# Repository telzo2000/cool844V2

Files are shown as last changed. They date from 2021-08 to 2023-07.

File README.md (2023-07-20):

# cool844V2

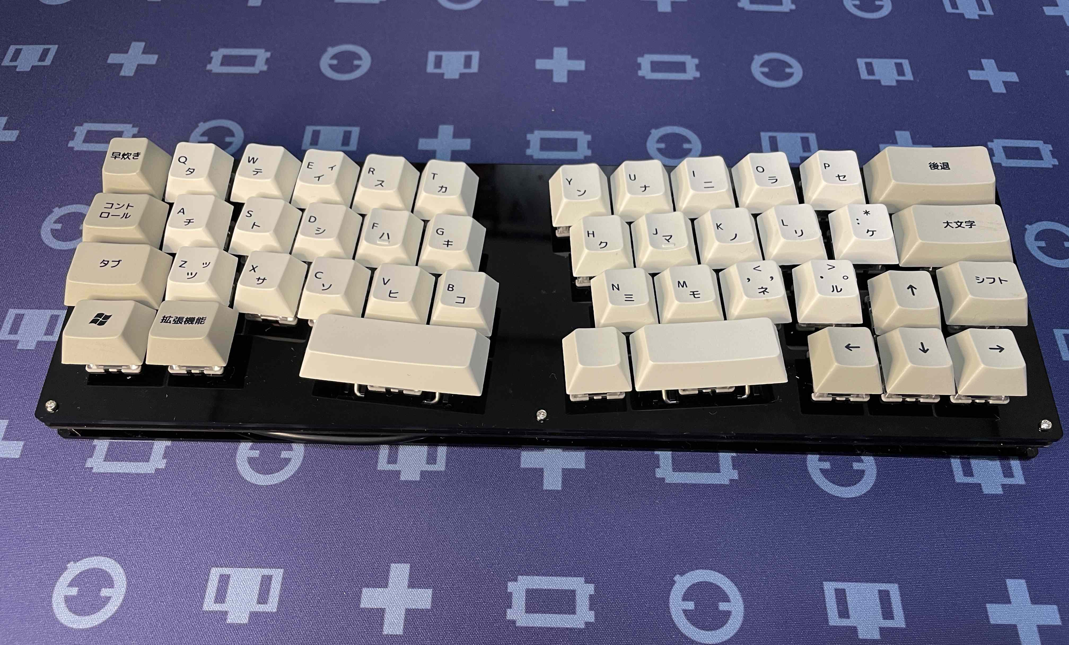
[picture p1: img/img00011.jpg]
<br>
cool844V2は、cool844の改良版を構想する過程で生み出された汎用ケースを使用しない40％アリス配列キーボードです。<br>
余った汎用ケースを再利用する目的で作った、cool844ですが、汎用ケース自体の背の高さから、パームレスト等が必要となり、不便と感じました。<br>
cool844で行った40%アリス配列は、使い勝手が良かったので、さらに使いやすく単体で使うことを構想したのが、cool844V2です。<br>
汎用ケースに収納していたcool844で感じていた高さの問題は、cool844V2でなくなりました。
REMAPによって、自作キーボードにおけるキーレイアウトは簡単に変更できるものとなりました。
これまでもファームウェアを書き換えれば、キーレイアウトの変更は可能であり、市販されているきーボードで感じていた不満を解消できました。
より個人に使いやすく設計されたキーボードとして自作キーボードは残っていくと思います。その一つとして、cool844V2があります。
<br>
今後、LEDの装着方法の見直し、単体として利用ができて、さらに汎用ケースにも収納できるハイブリッドとしての改良を行います。<br>
上記までのcool844V2をver.2.0として、汎用ケースでも、アクリル積層密閉型ケースでも使用できるcool844V2がver.2.1です。<br>
ver.2.1はPCBより下の部分に、ゲタと名付けた部品を介して、汎用ケースに装着できます。気に入った汎用ケースが入手するまでは、標準のアクリル積層密閉型ケースで使用することができます。<br>
ver.2.0もゲタを使用することで、汎用ケースに装着できます。ただし、USBタイプC基板の取り付けが変更になります。また、汎用ケースを使用しない時に、従来のボトムプレートが使用できないので、切り込みの入った別のボトム方レートを使用します。<br>
ver2.0用のゲタとボトムプレートも頒布できるように用意します。<br>
ver.2.1は自分用、最初に用意したものは透明なトッププレートですが、頒布用は黒色となります。ただし、限定ですが、透明なトッププレートも同封した豪華セットも用意します。

<br>
# ビルドガイド

[こちら（ver.2.1）](https://github.com/telzo2000/cool844V2/blob/main/buildguide_for_cool844V21.md)になります。
[English version(ver.2.1)](https://github.com/telzo2000/cool844V2/blob/main/buildguide_for_cool844V21_english.md)
<br>
[こちら（ver.2.0）](https://github.com/telzo2000/cool844V2/blob/main/buildguide_for_cool844V2.md)になります。<br>
<br>

# 今後の予定
20210813 V2(ver.2.0)を頒布しました。<br>
20210815 V2(ver.2.1)を発注しました。<br>
20210830 頒布用にアクリル部品の追加を発注しました。<br>

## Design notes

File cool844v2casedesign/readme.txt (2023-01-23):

These are the components of the keyboard case.
The red line is the cutline.

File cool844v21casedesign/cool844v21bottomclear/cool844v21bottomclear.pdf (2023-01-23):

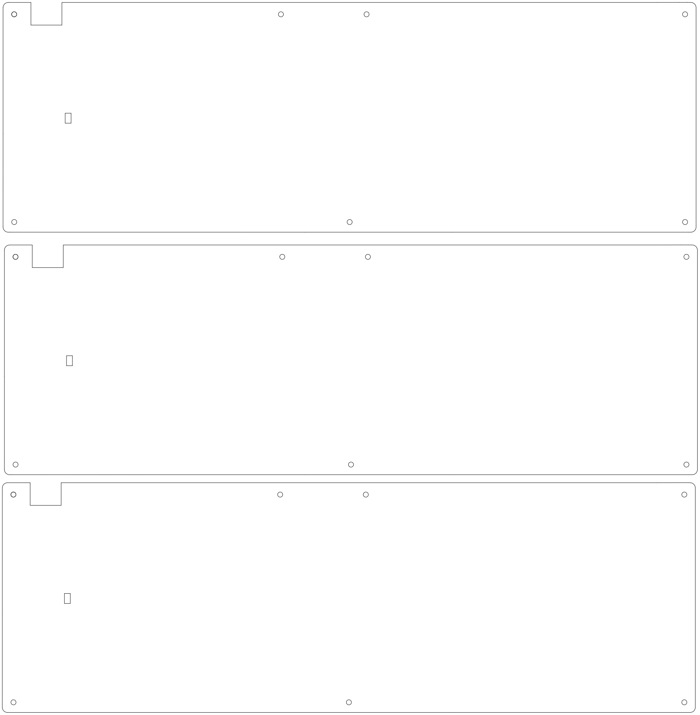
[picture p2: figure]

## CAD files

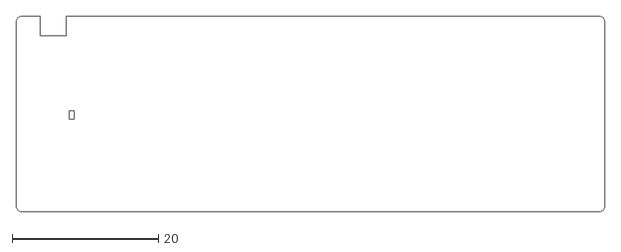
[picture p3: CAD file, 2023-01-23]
cool844v21casedesign/cool844v21bottomclear/cool844v21bottomclear.dxf
80.4 x 26.7

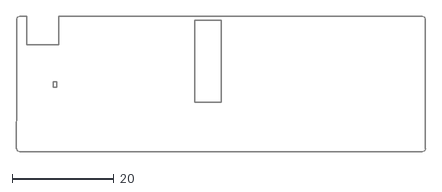
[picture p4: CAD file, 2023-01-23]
cool844v21casedesign/cool844v21getaclear/cool844v21getaclear.dxf
80.4 x 26.7

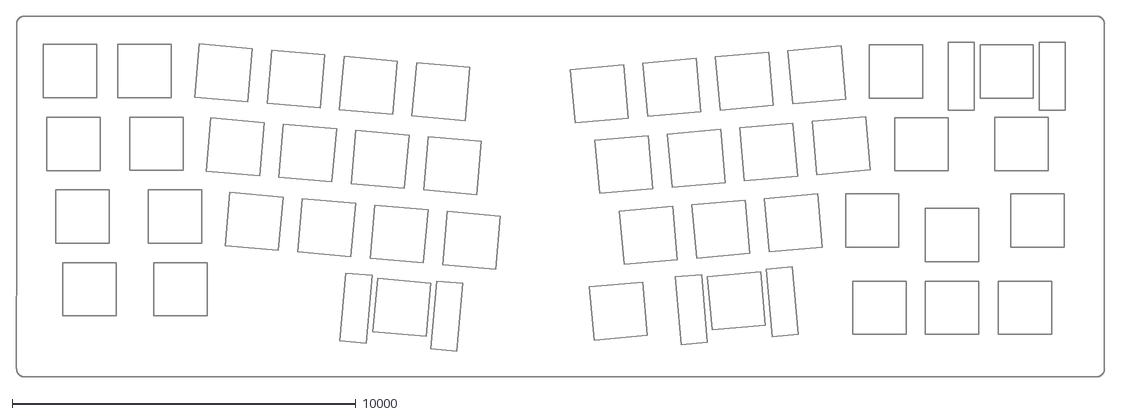
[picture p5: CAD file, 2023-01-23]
cool844v21casedesign/cool844v21topblack/cool844v21topblack.dxf
31667.0 x 10503.3

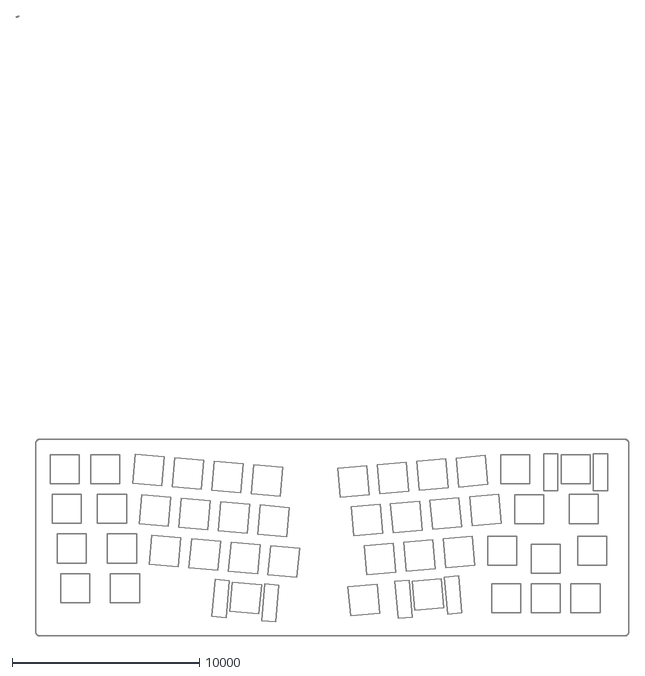
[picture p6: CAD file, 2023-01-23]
cool844v21casedesign/cool844v21topplate/cool844v21topplate.dxf
32707.8 x 33092.1

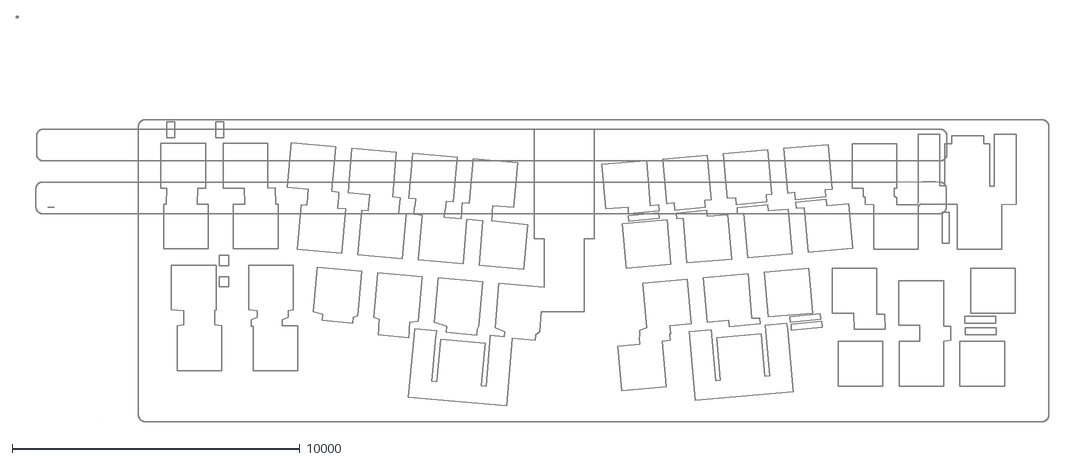
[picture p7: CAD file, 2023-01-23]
cool844v21casedesign/cool844v21topunderplate/cool844v21topunderplate.dxf
35920.0 x 14099.2

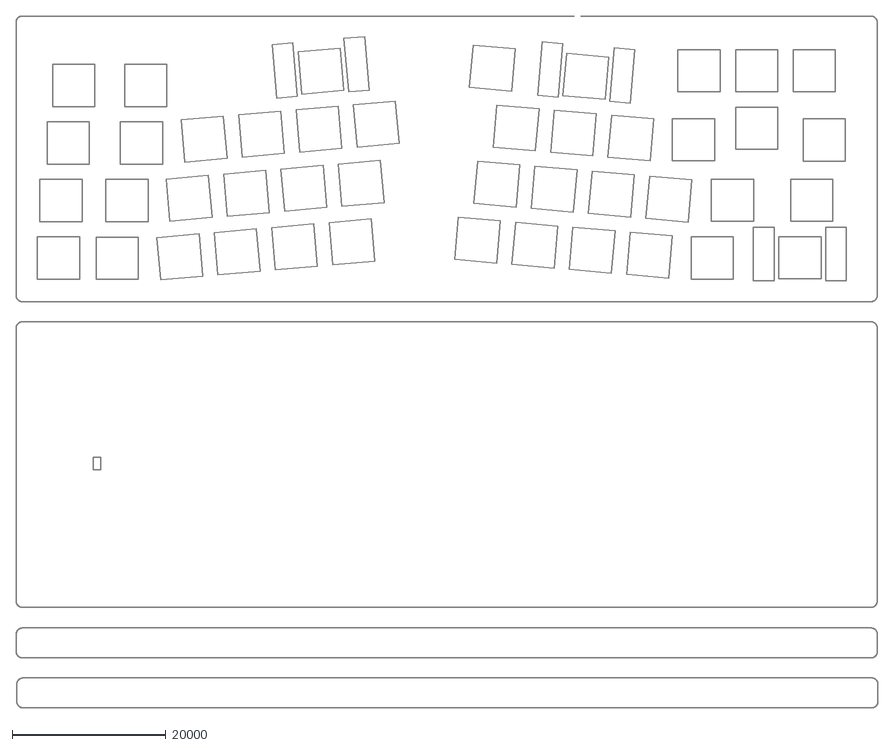
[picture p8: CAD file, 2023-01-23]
cool844v2casedesign/cool844v20case01.dxf
112300.8 x 90138.6

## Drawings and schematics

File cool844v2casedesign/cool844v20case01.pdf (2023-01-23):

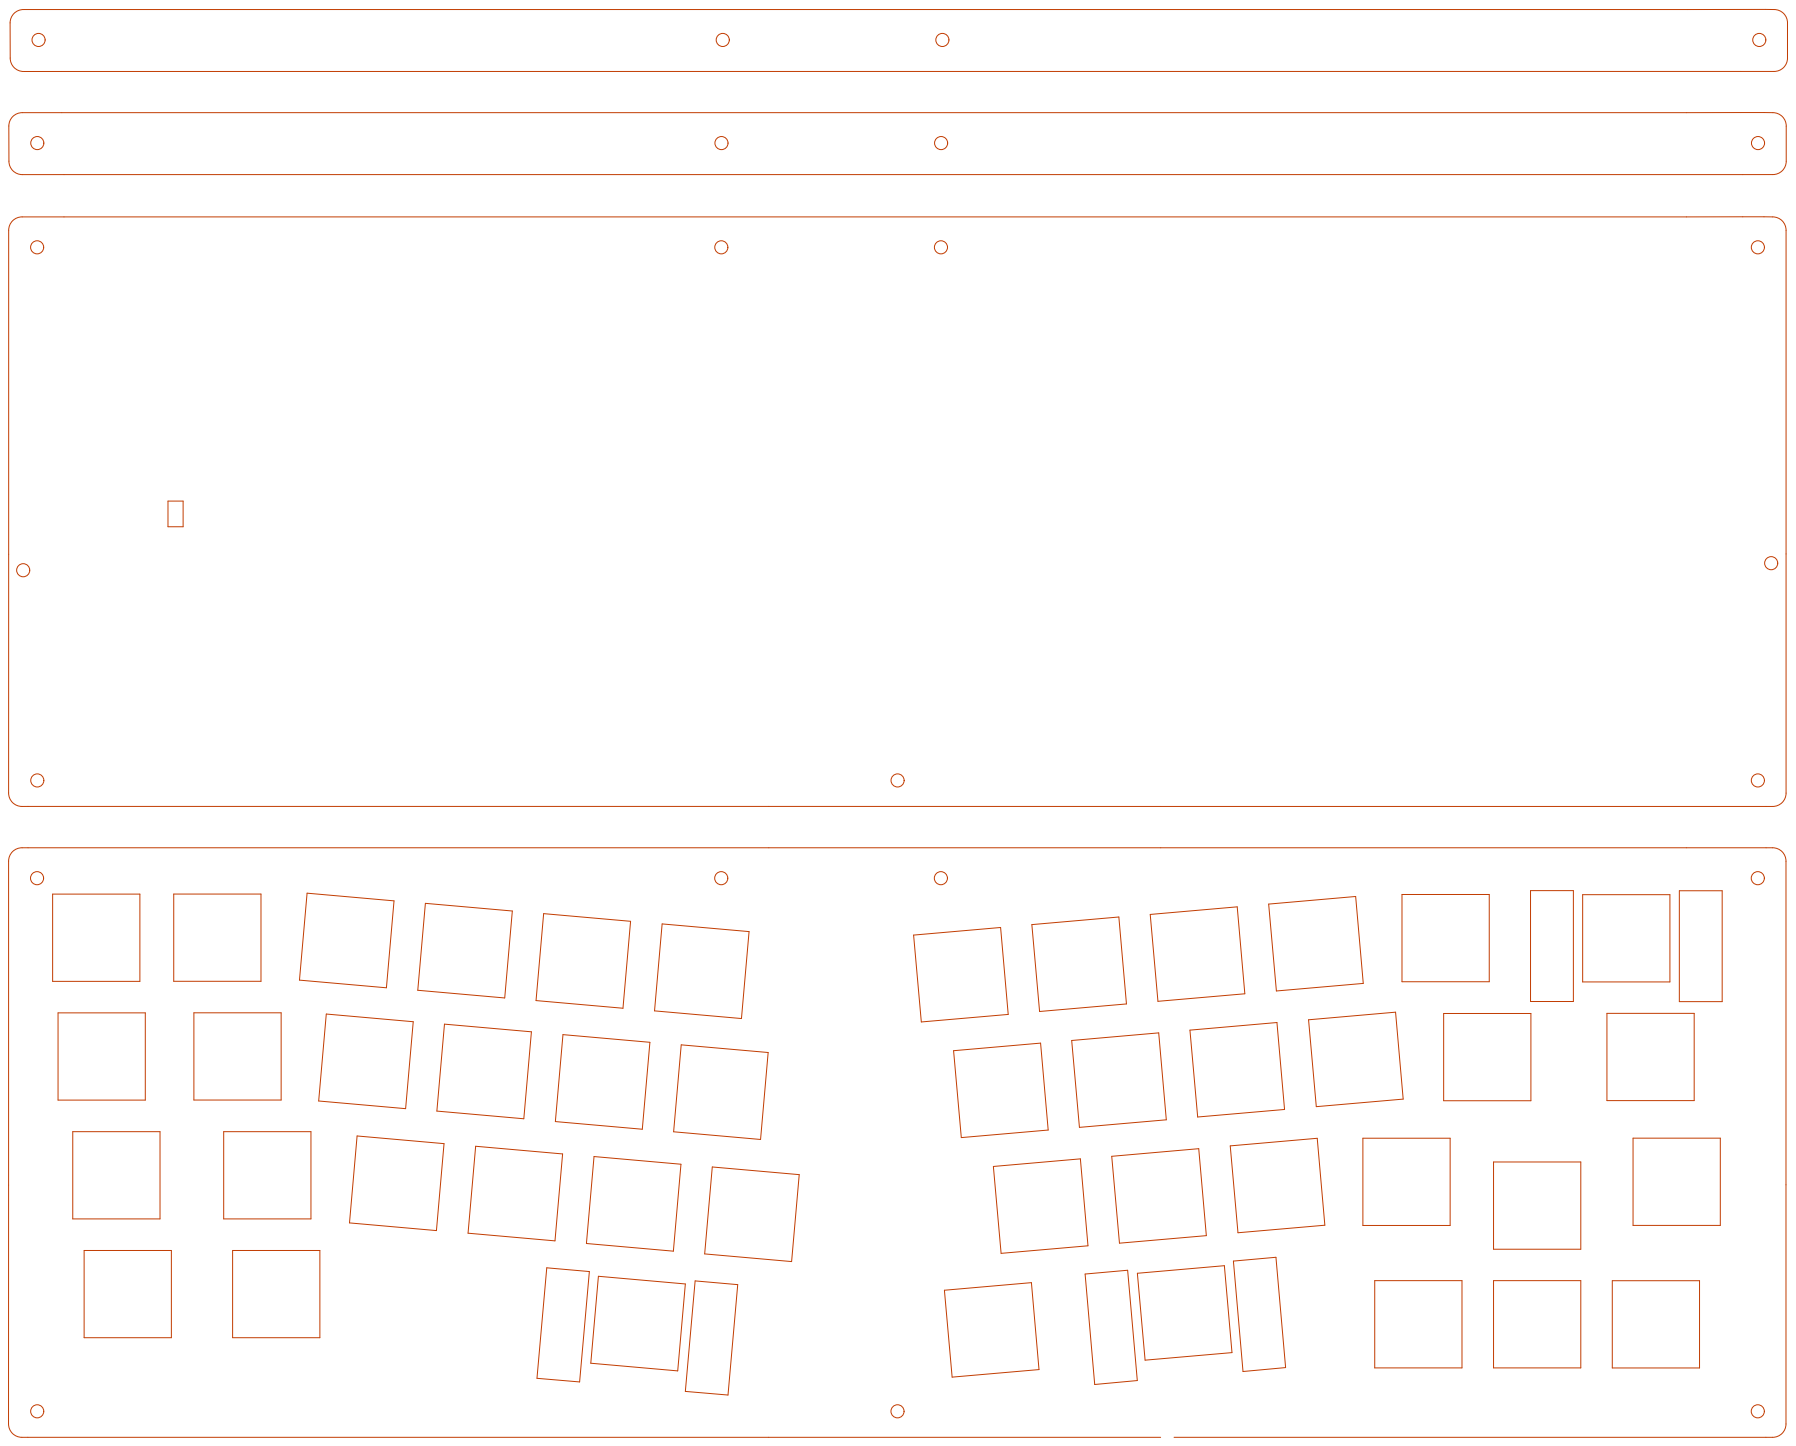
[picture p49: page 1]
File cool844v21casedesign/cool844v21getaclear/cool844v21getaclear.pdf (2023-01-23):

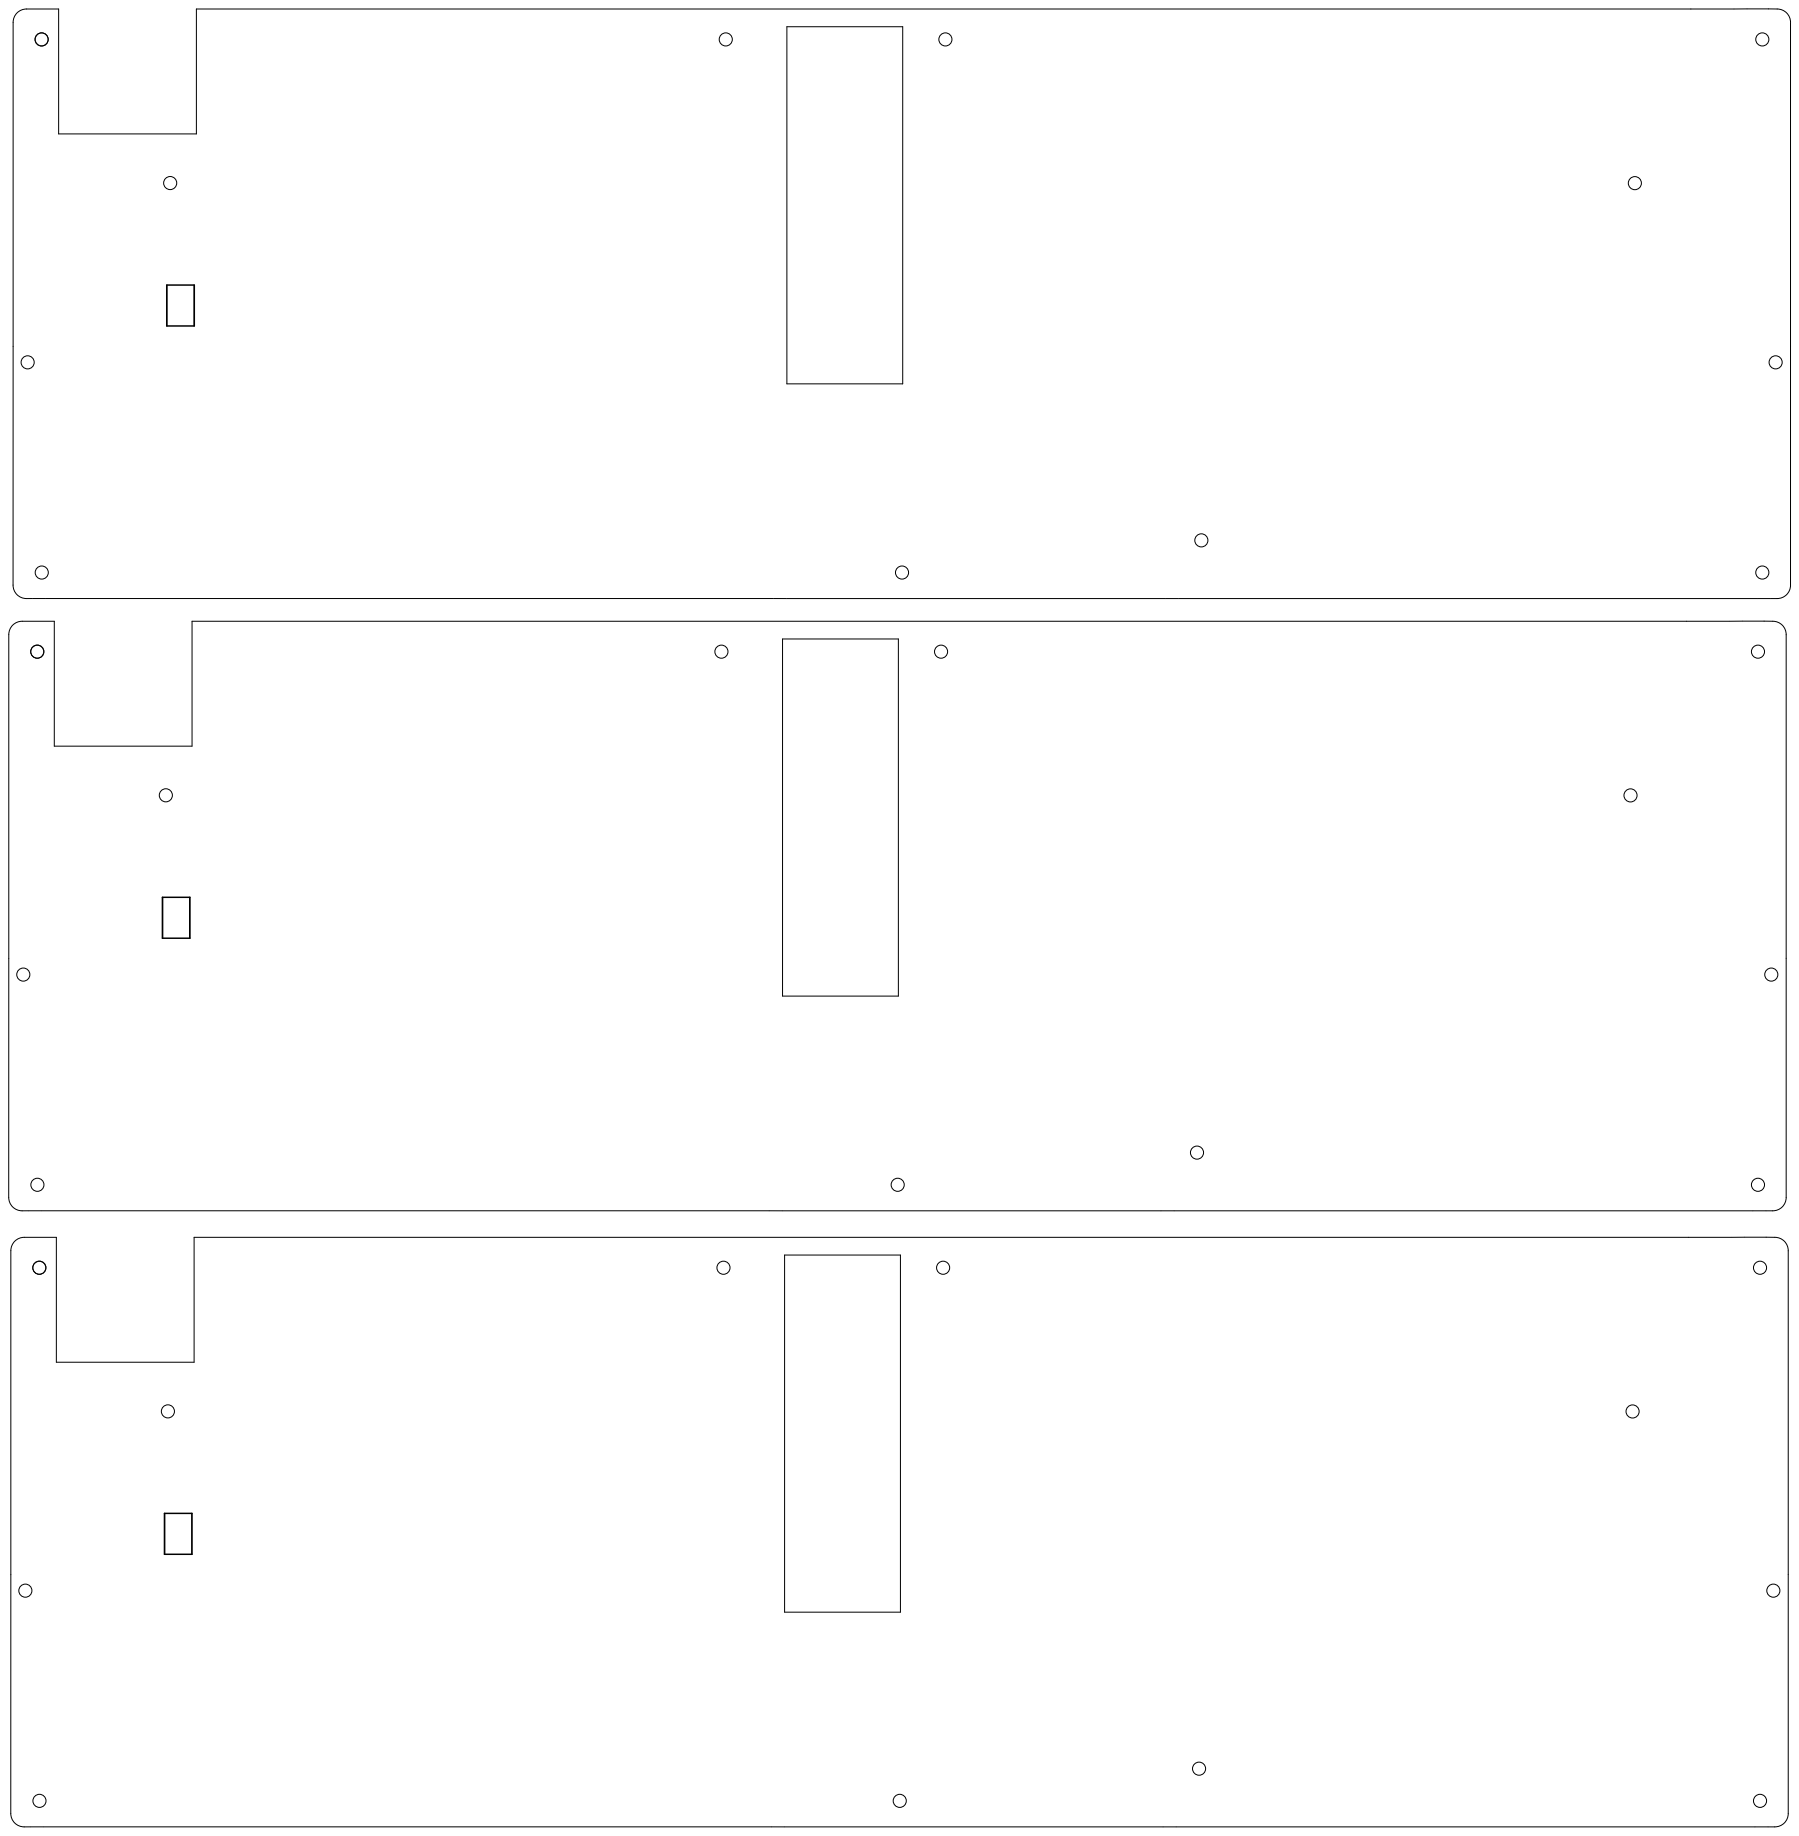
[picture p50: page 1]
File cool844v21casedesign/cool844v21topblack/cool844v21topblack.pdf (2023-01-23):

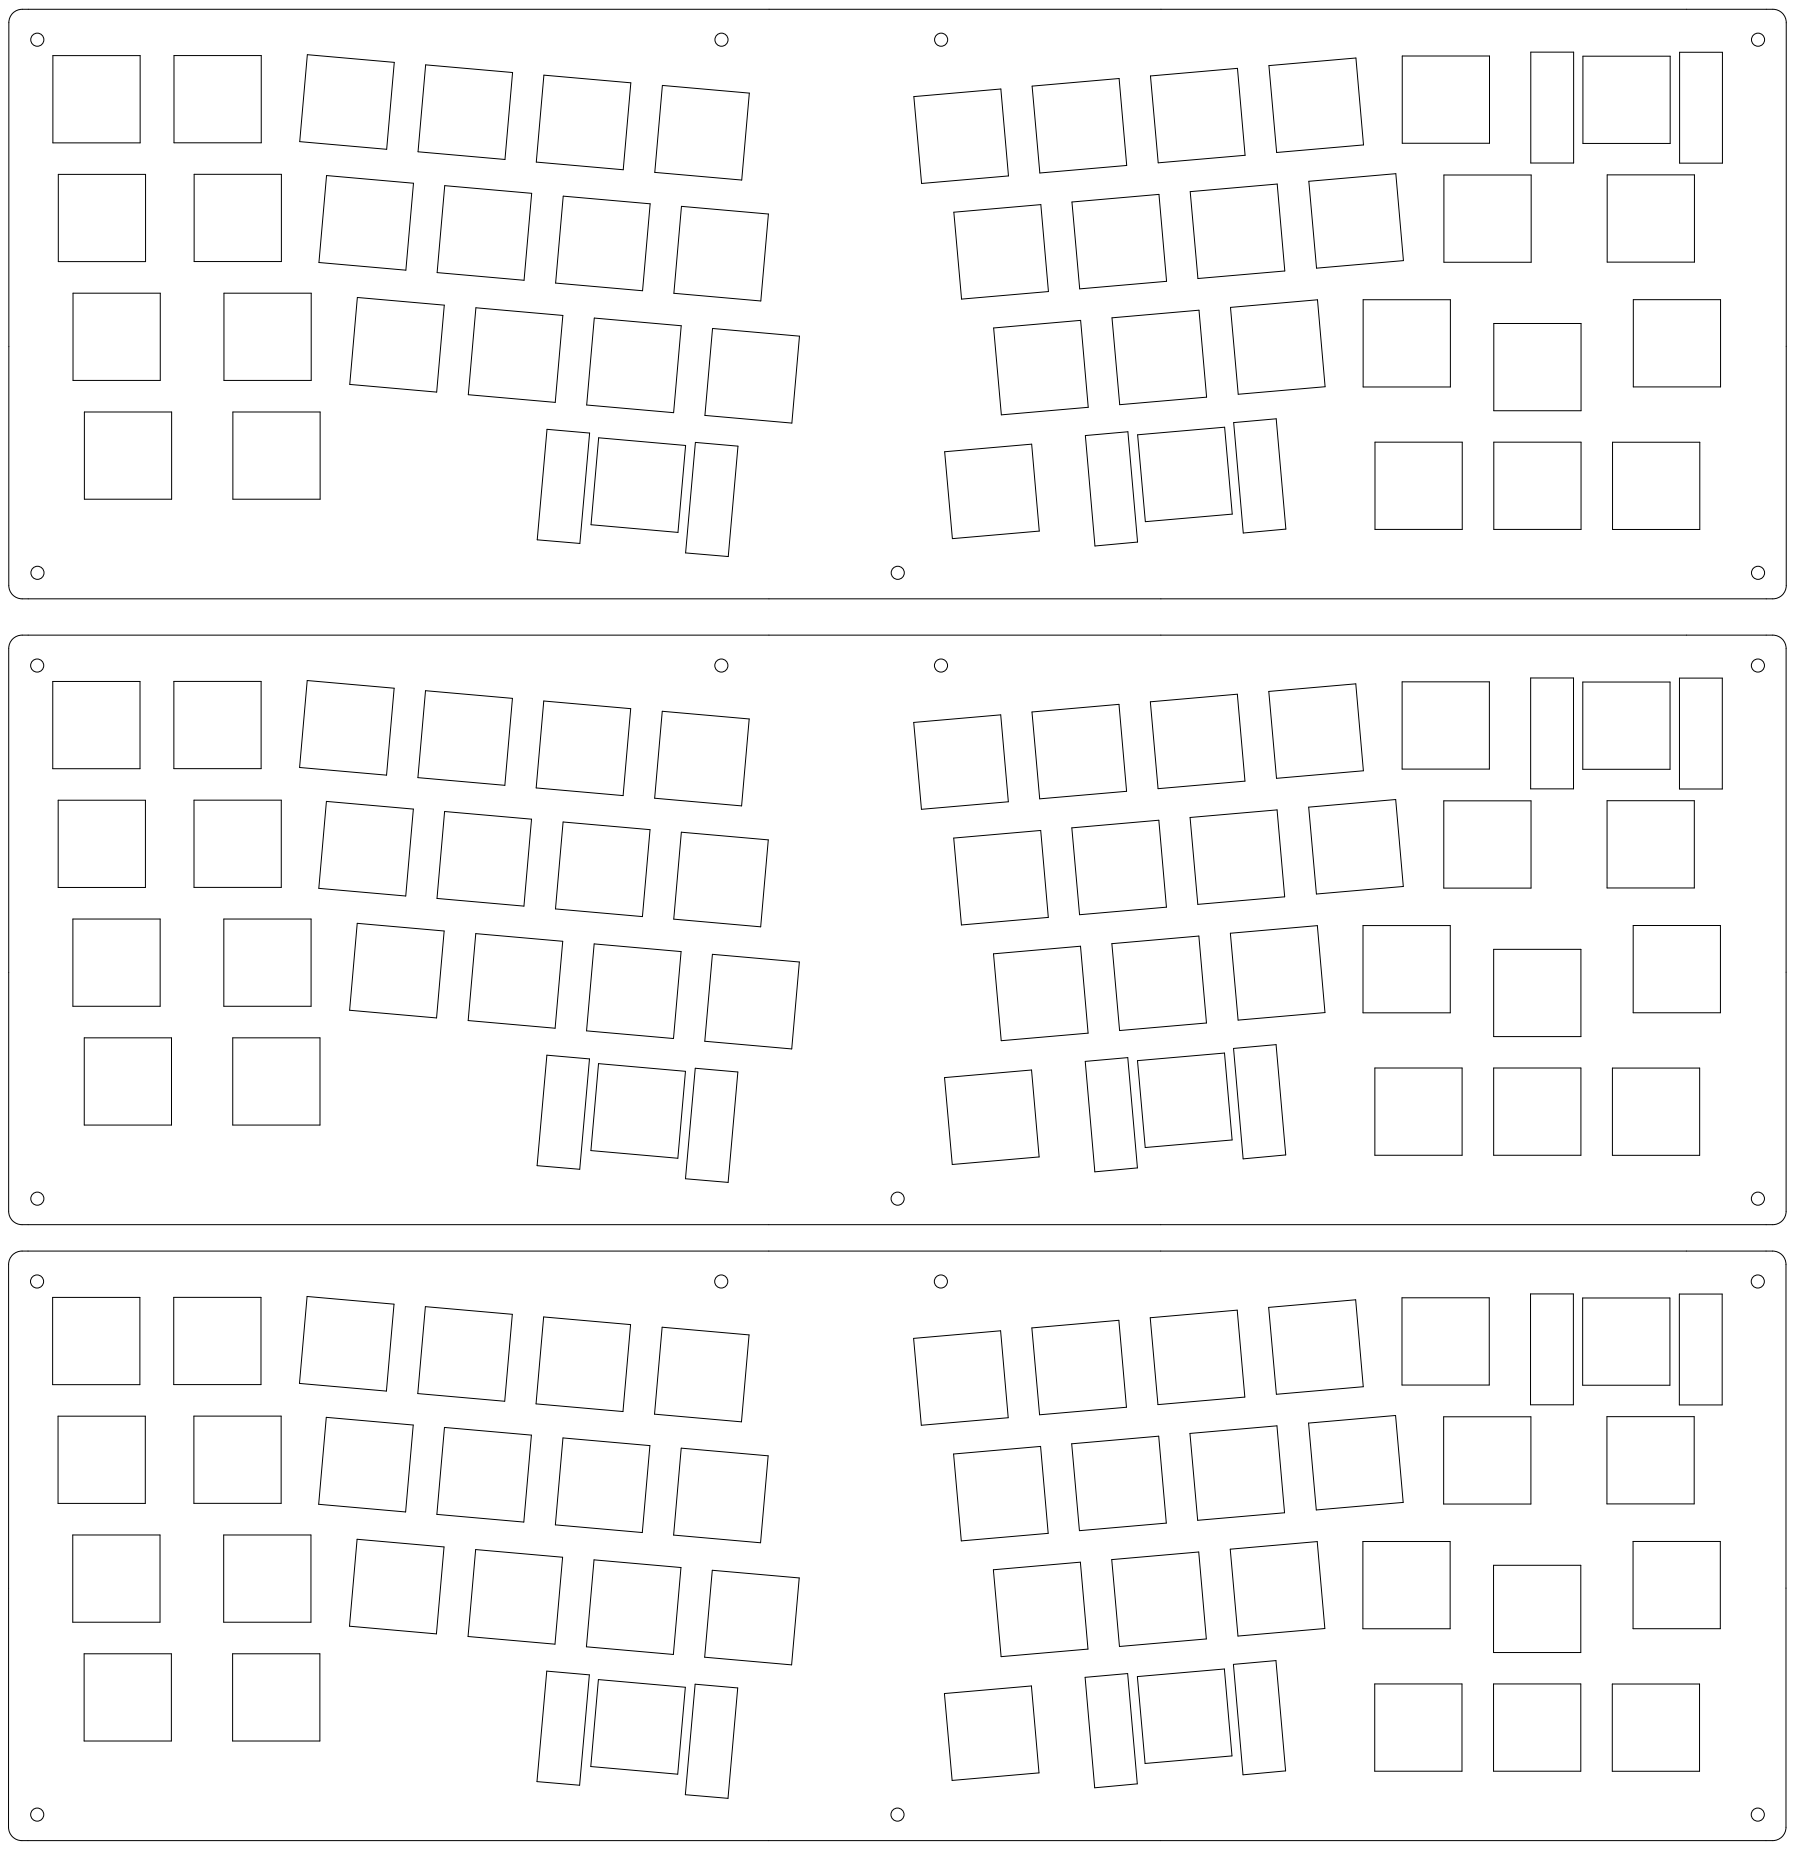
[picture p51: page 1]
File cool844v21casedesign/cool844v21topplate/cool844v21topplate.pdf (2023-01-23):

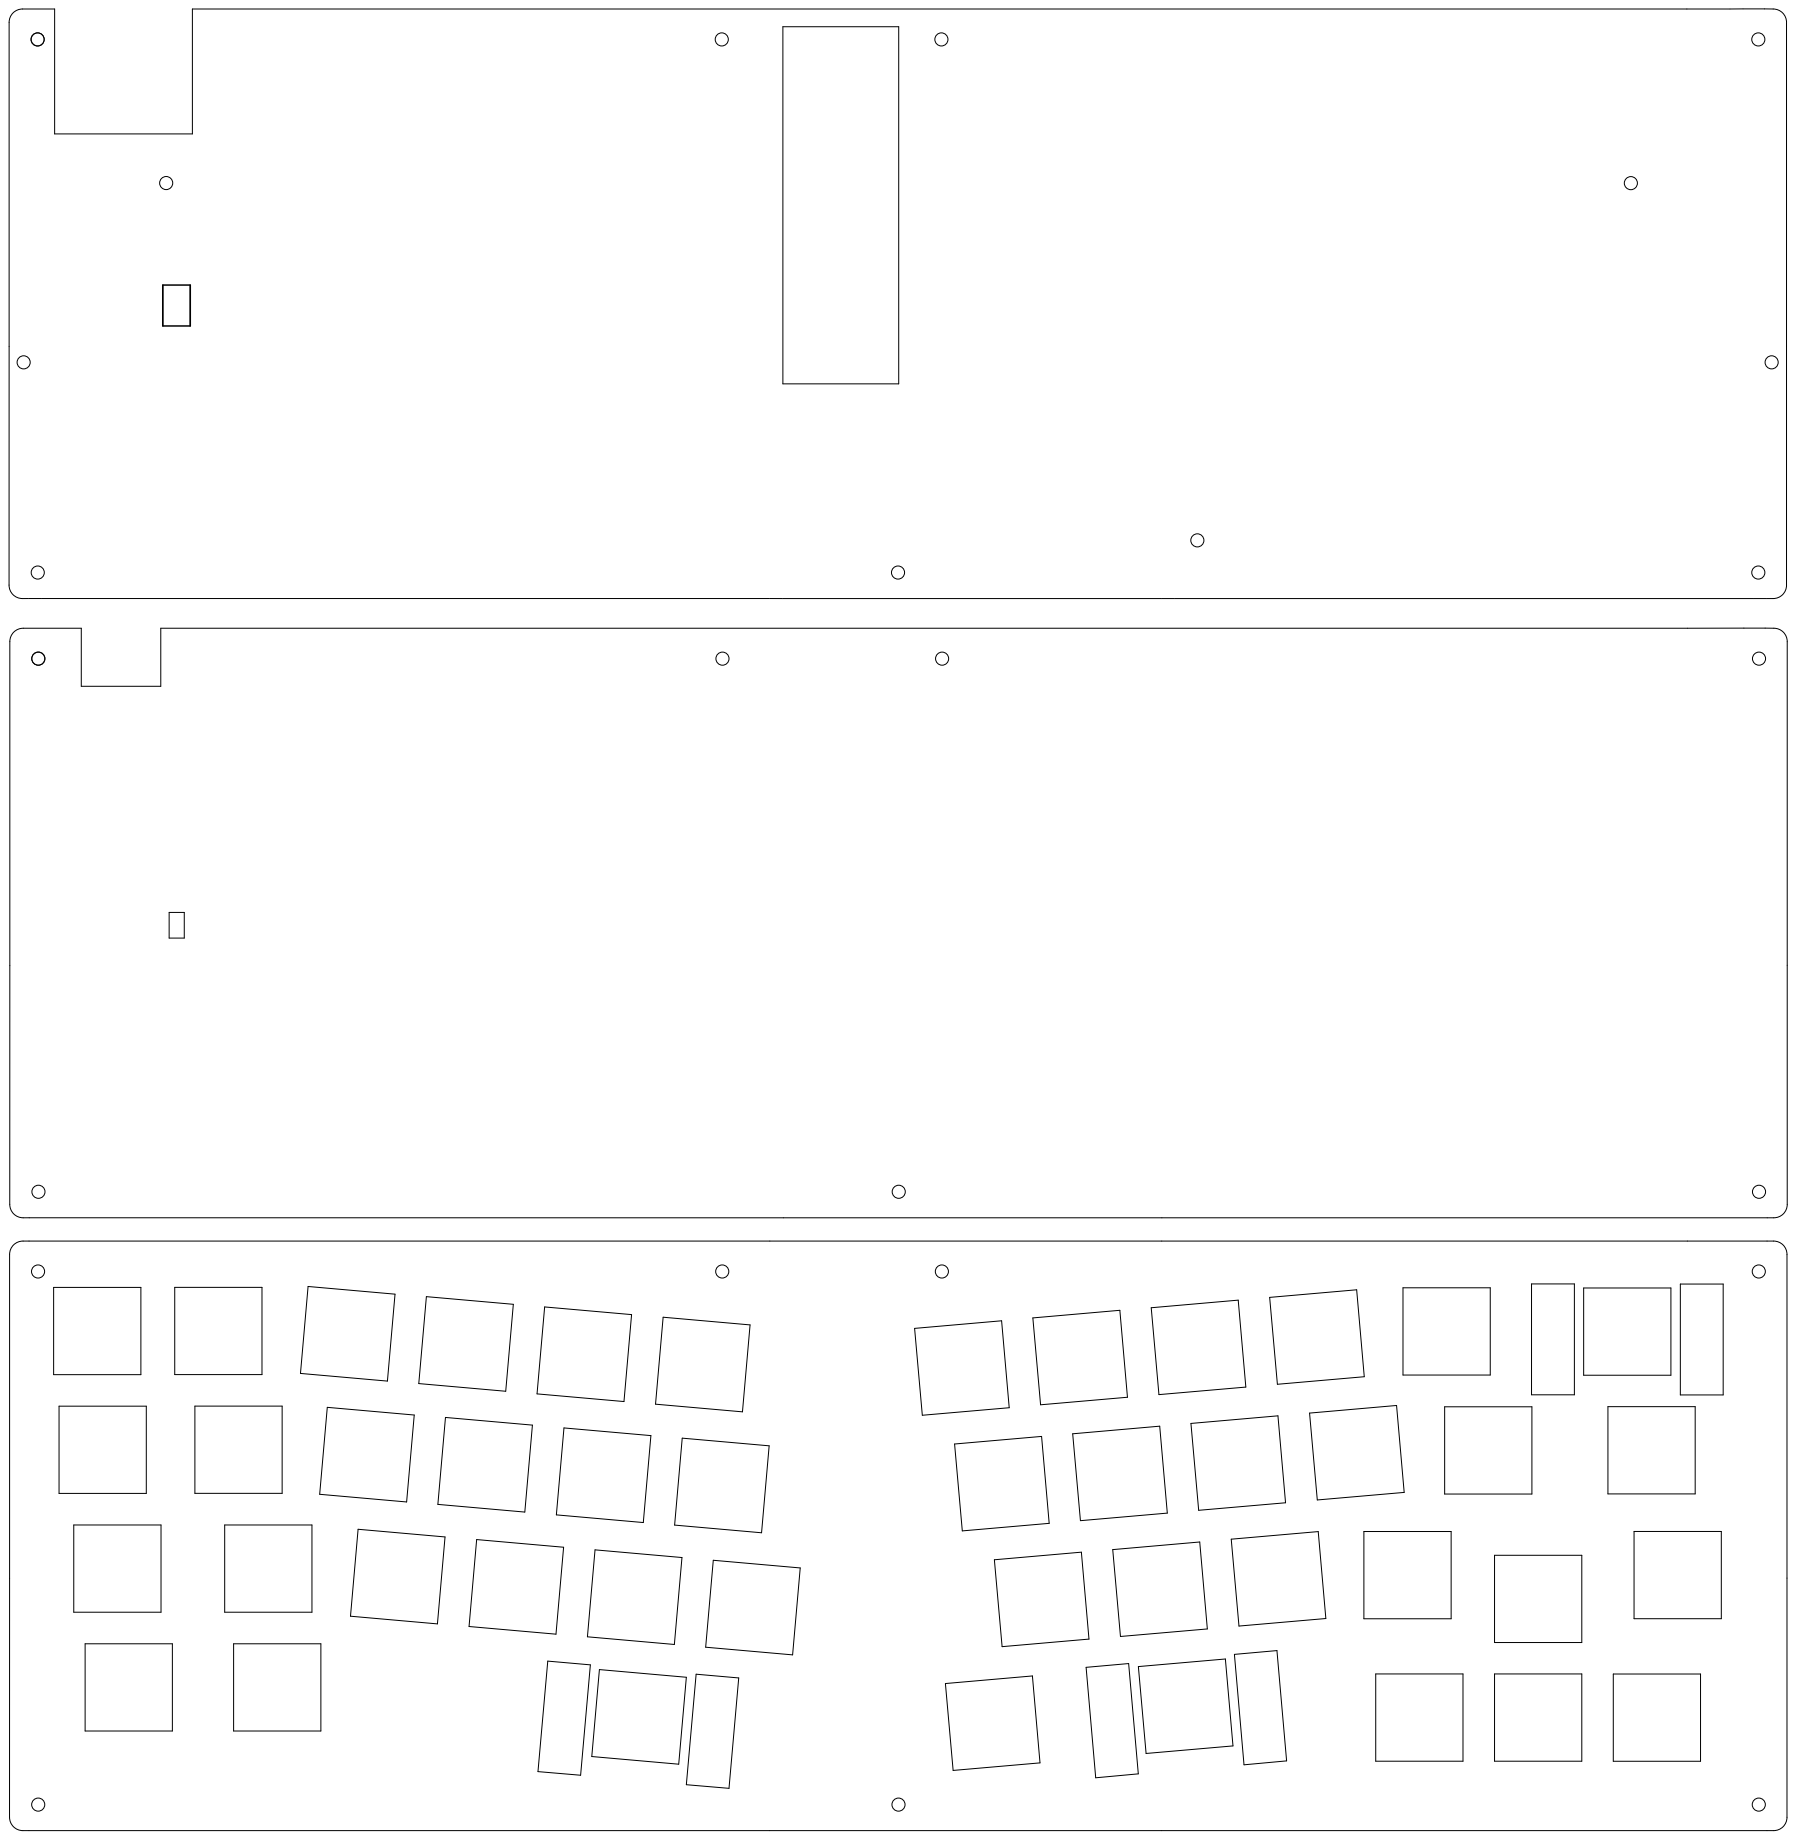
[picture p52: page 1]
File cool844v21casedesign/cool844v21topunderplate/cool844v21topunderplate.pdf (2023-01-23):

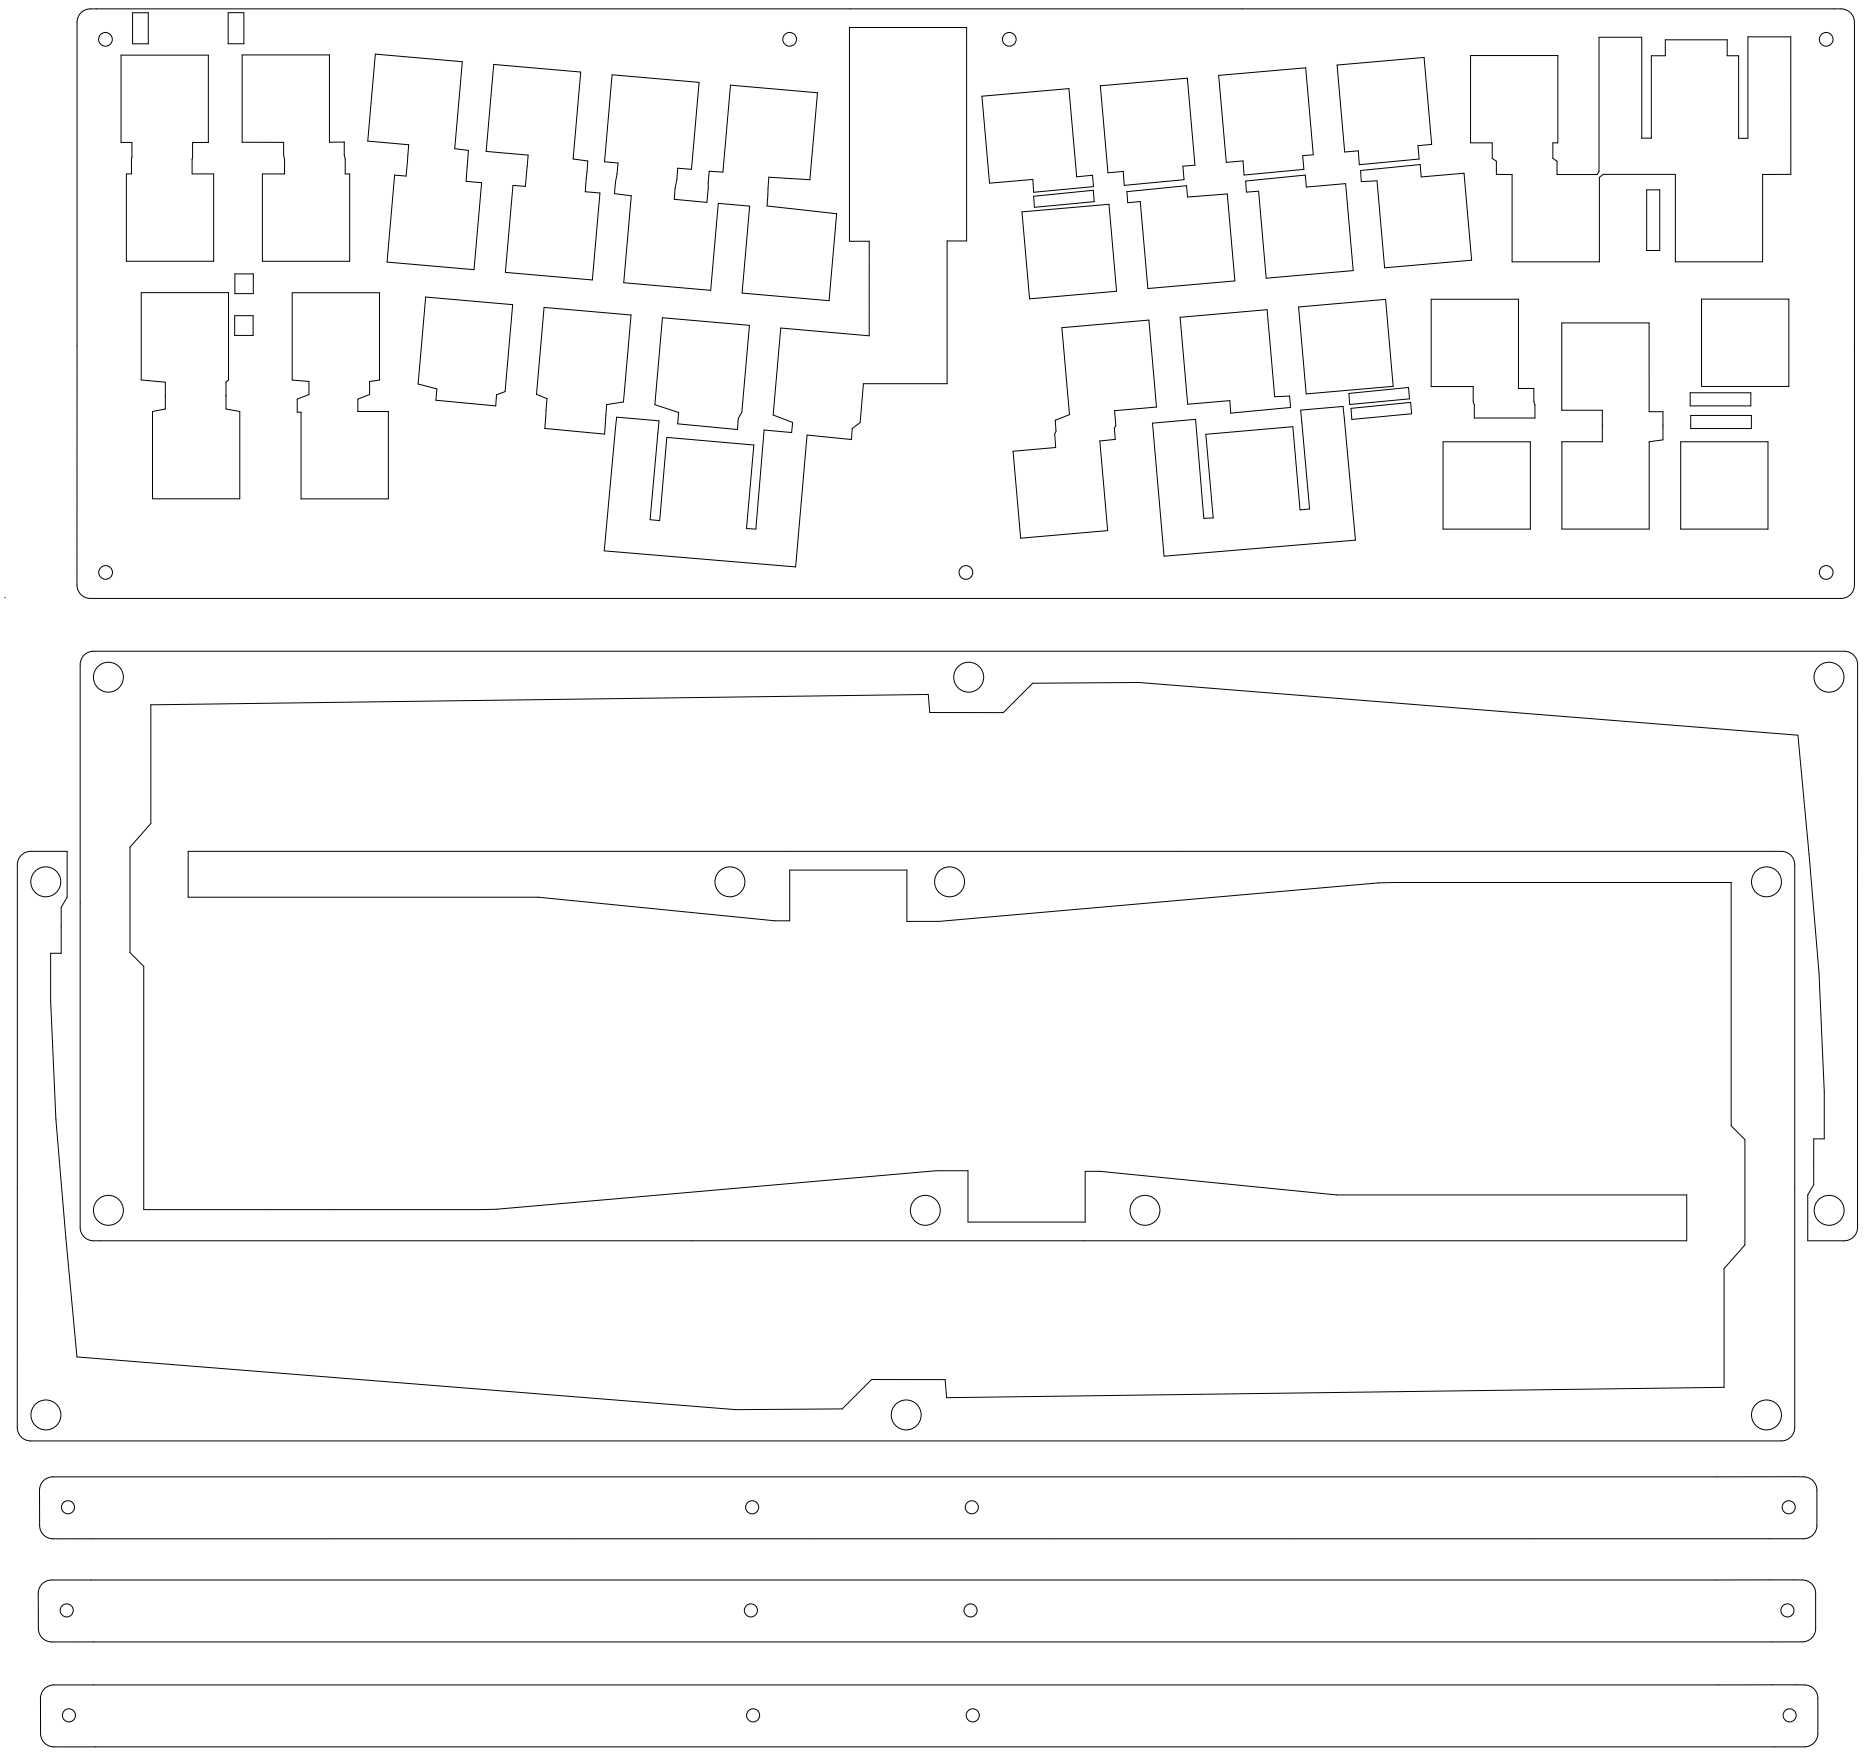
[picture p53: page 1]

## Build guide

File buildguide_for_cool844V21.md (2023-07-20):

# cool844V2ビルドガイド（ver.2.1対応)

### ＜特徴＞
cool844V2（ver.2.1）はm.kiが設計した自作キーボードです。
<br>
60%自作キーボード用の汎用ケースに収納して使うことは、
これまでのcool844と同じです。<br>
また、汎用ケースに収納しないで、単体でも使用できるよう、
アクリルのボトムプレート等が付属しています。<br>
その日の気分によって、気に入った汎用ケースに収納して使ったり、
アクリル積層よる密閉型ケースで使ったりしてください。<br>
<br>

cool844V2　アクリル積層密閉型ケース
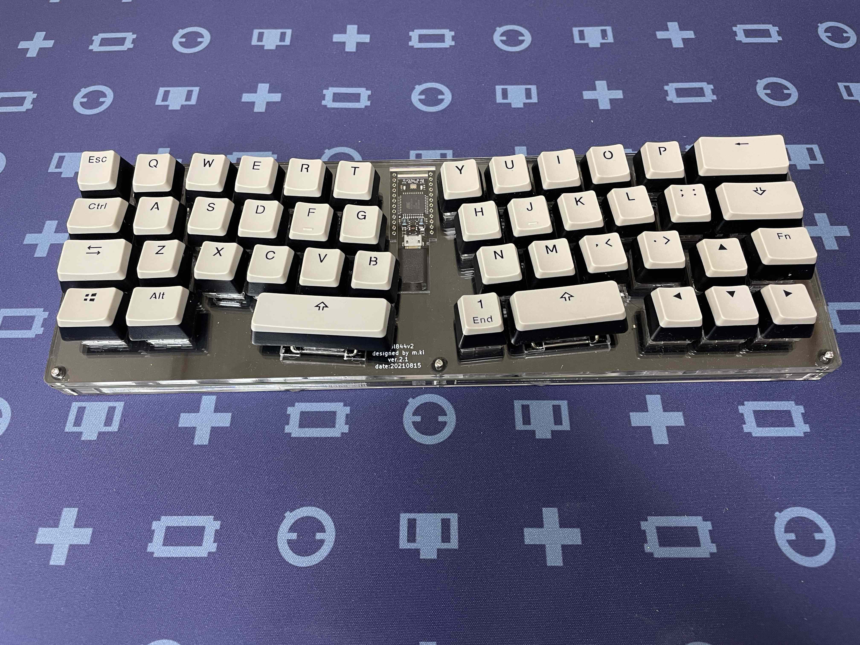
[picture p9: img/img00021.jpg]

cool844V2　別売り60%汎用ケース（木製ケースを使用）
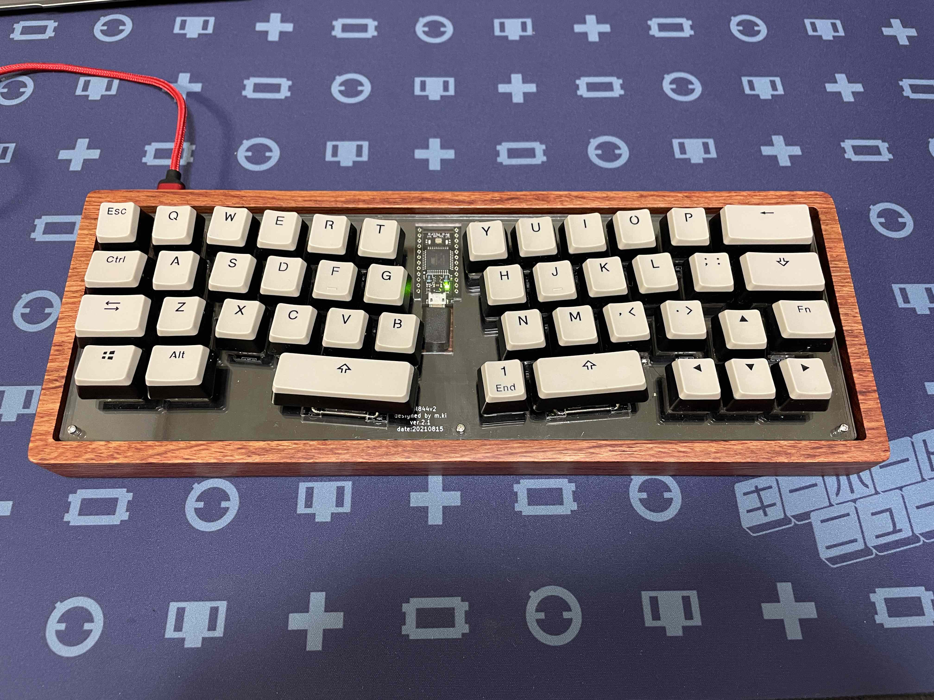
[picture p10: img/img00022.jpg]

cool844V2　ケース収納前
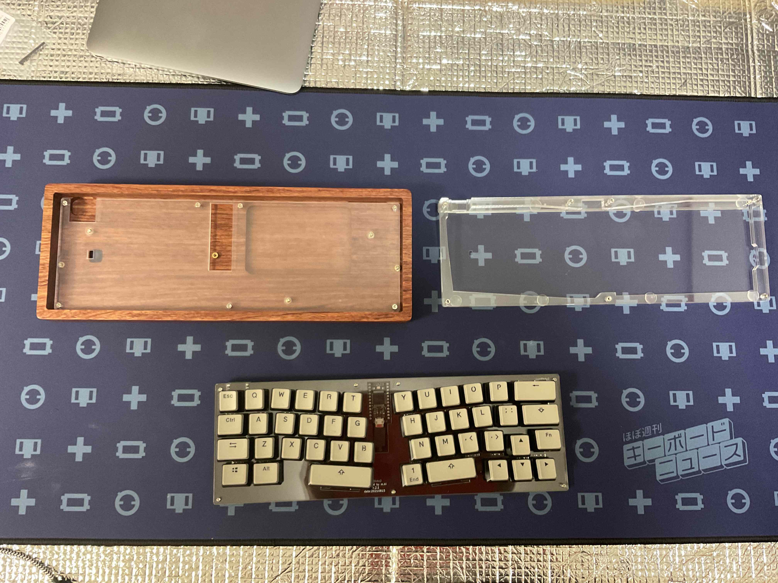
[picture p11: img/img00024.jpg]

注意　上の完成画像で使われている透明なスイッチプレートは、
豪華セットに同封されるものです。<br>
基本セットでは、黒色のスイッチプレートとなり、落ち着いた感じになります。<br>
<br>
# 0　参考
cool844V2は基本、cool844と同じです。組み立てに困りましたら、cool844の[ビルドガイド](https://github.com/telzo2000/cool844/blob/main/buildguideforcool844.md)を参考にしてください。<br>
必ず一読してから、組み立てを行ってください。
<br>

# 1　部品の確認
本品はスイッチプレート、ミドルプレート（２種３枚）、PCB、ボトムプレート大、ボトムプレート小（３枚）、
”ゲタ” 換装用アクリルプレート　１枚、
マイクロUSB端子（オス）付きケーブル、M2スペーサー5.5mm７本、M2ねじ８mm７本、M2ねじ４mm３本、M2ねじ12mm4本で構成されています。<br>
<br>
次のものは各自でご用意ください。<br>
ダイオード（リードタイプ）44個、スイッチソケット44個、リセットスイッチ１個、pro micro１個、スプリングピンヘッダ（マックエイトコンスルー）２個、
スタビライザー２U ３個、USBタイプC基板１個の他、<br>
お気に入りのキーキャップセットとなります。<br>
<br>
60％汎用ケースに換装するときには、<br>
M2スペーサー３mm ７本<br>
M2ネジ４mm　12本<br>
が必要となります。
<br>

<br>

# 2　ダイオードのハンダ付け
PCB基板の下面（基板の右隅に「cool844V2」と印字されている面が上面です）に、「diode」と印字されています。印字されている面から差し込んで、上面からはんだ付けしてください。向きに注意してはんだ付けしてください。<br>
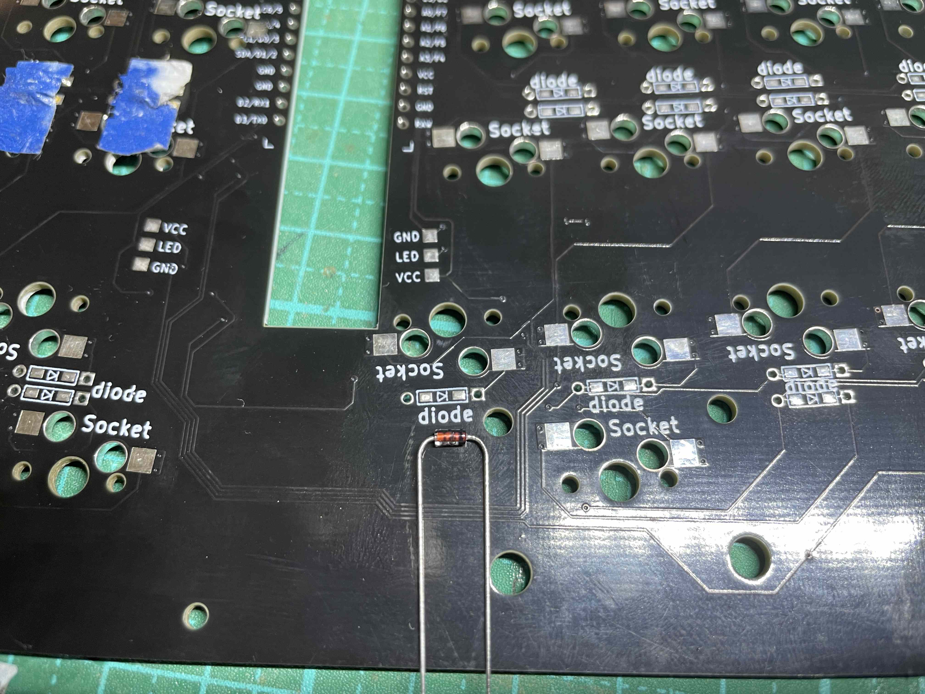
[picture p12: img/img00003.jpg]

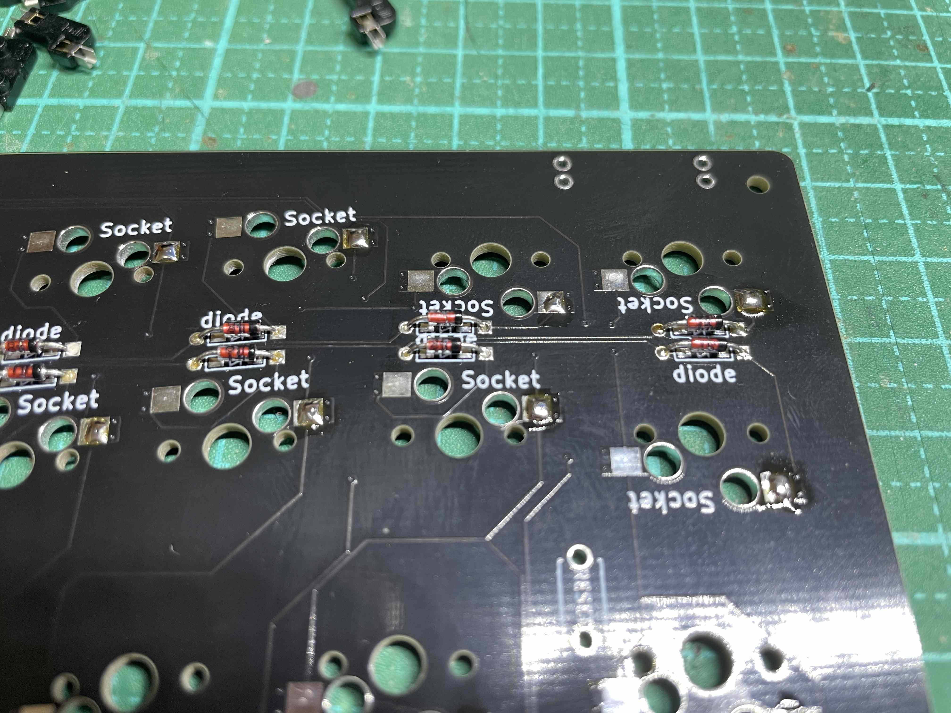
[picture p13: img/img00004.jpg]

<br>

# 3　スイッチソケットのハンダ付け
PCB基板の下面に、「Socket」を印字されています。印字が見えないようにスイッチソケットを乗せて、ハンダ付けをしてください。スイッチソケットには向きがあります。向きを間違えると、キースイッチが入らなくなります。<br>
正しい向きに乗せた場合
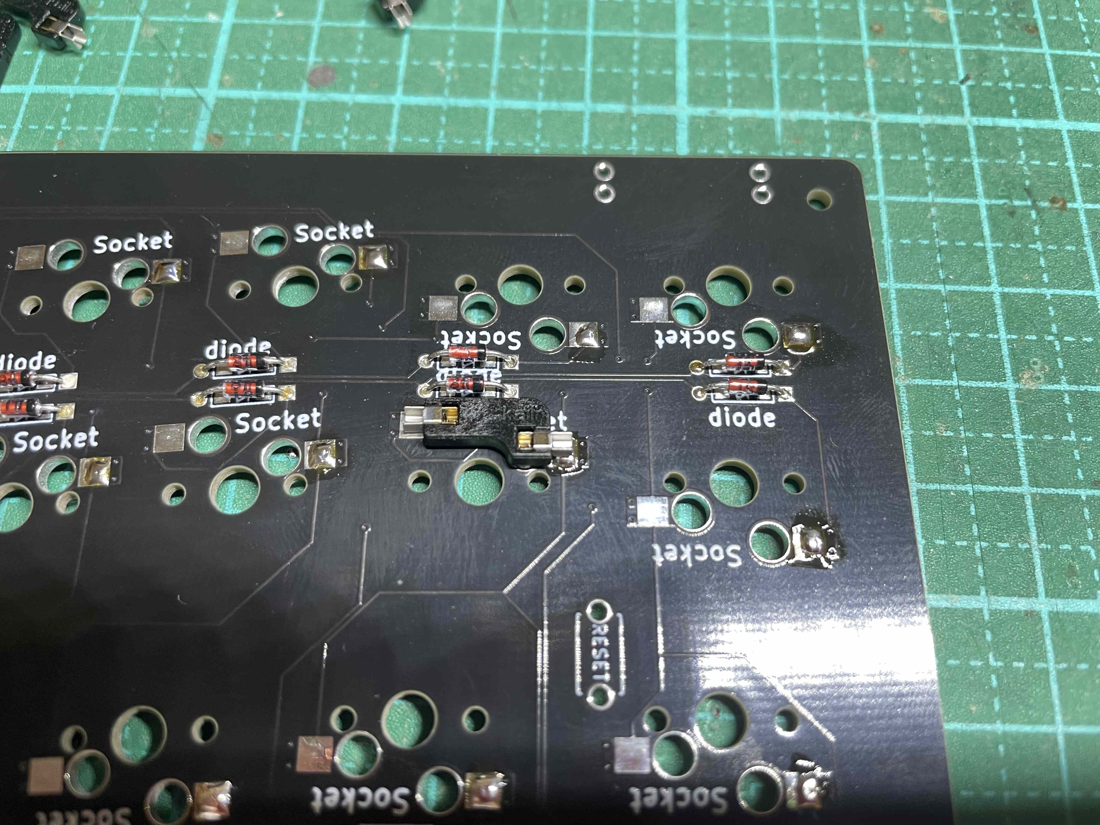
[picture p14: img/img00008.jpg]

間違った向きに乗せた場合（「Socket」の印字が見えます）
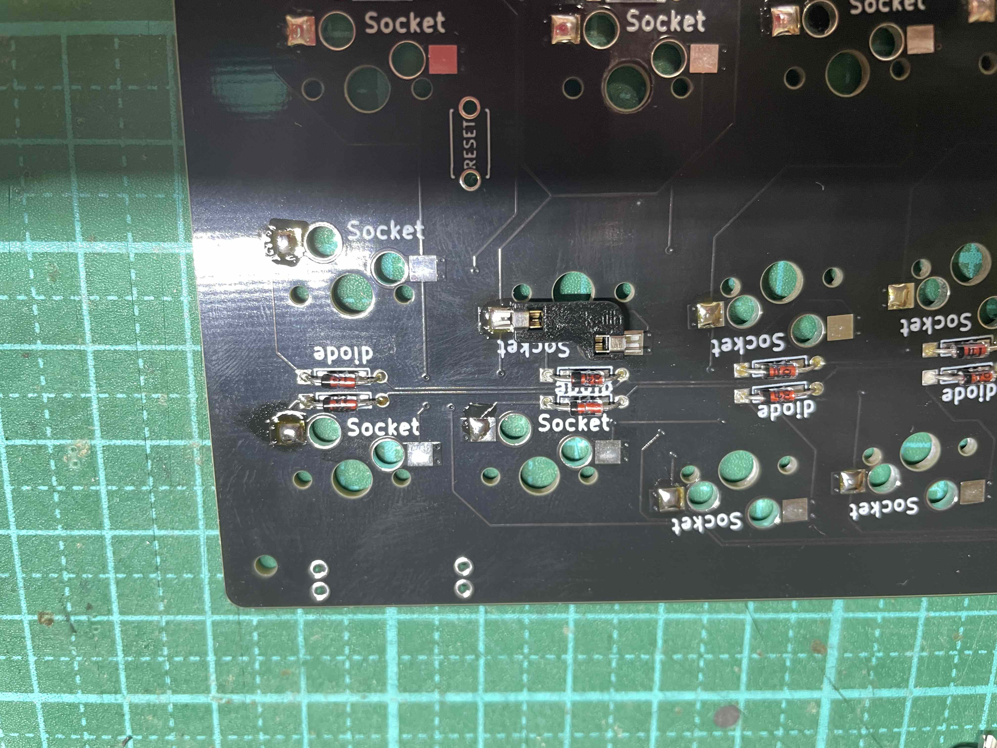
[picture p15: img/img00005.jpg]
間違った向き

<br>
# 4　リセットスイッチのハンダ付け
PCB基板の下面に、「RESET」と印字されています。印字が見ねないようにリセットスイッチを乗せて、上面からハンダ付けをしてください。<br>
<br>
# ５　pro microのハンダ付け
PCB基板の下面に、スプリングピンヘッダ２個をそれぞれ、差し込んでください。<br>
スプリングヘッダには側面に、小さな穴が空いています。
穴が空いている向きを揃える必要があります。
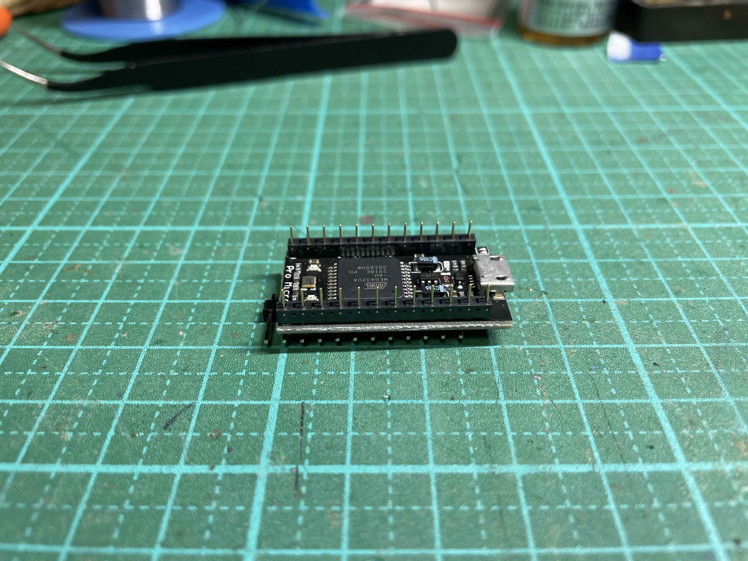
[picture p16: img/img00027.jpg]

スプリングピンヘッダにpro microを差し込んで、pro microとスプリングピンヘッダをハンダ付けをしてください。PCBとスプリングピンヘッダのハンダ付けは不要です。
pro microの向きに注意ください。<br>
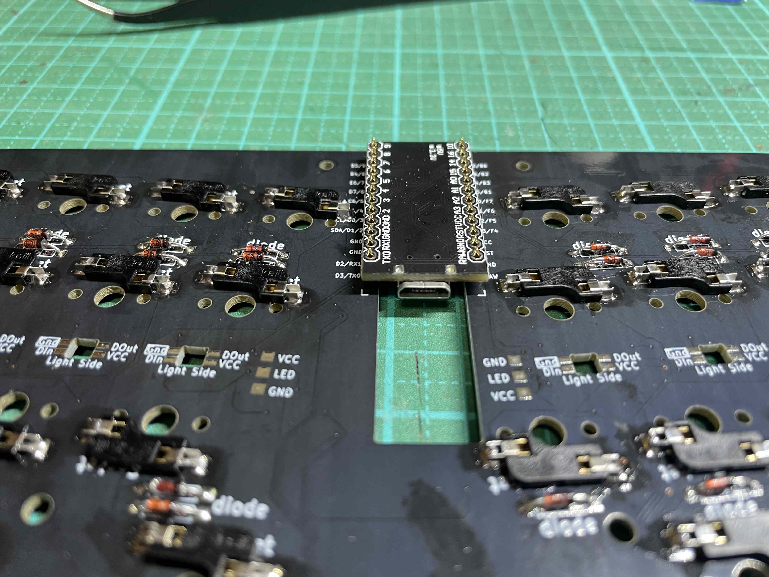
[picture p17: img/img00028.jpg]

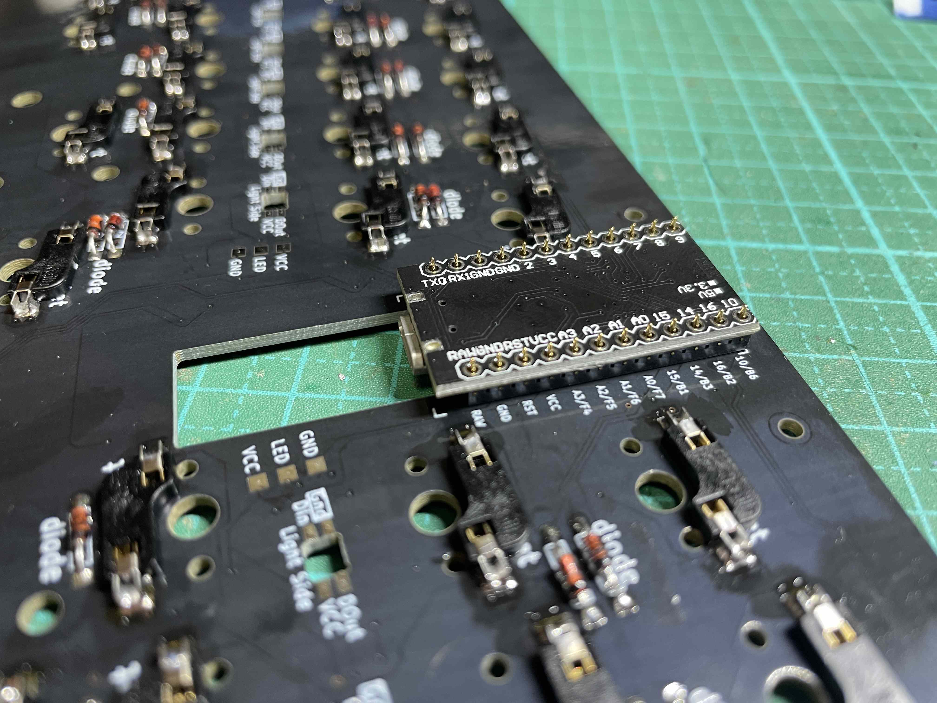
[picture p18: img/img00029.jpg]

<br>
# ６　ドーターボードの作成
付属のマイクロUSB端子（オス）付きケーブルを必要な長さに切ります。<br>
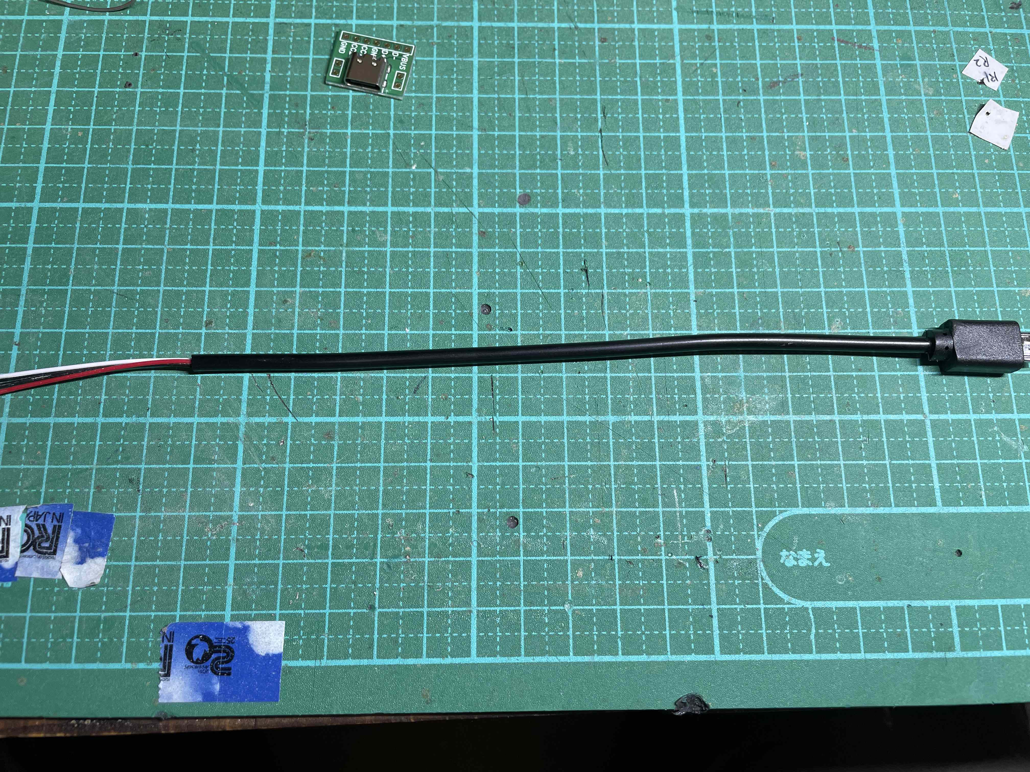
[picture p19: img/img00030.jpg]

最初に端子側から19cmほどのところで切ります。
その後、黒い皮膜が16cmほど、その先は３cmほど残してください。<br>
４色に分かれているケーブルの皮膜を剥いて、それぞれをUSBタイプC基板の端子にハンダ付けしてください。
赤色をVBUS、白色をD-、緑色をD+、黒色をGNDにつないでください。
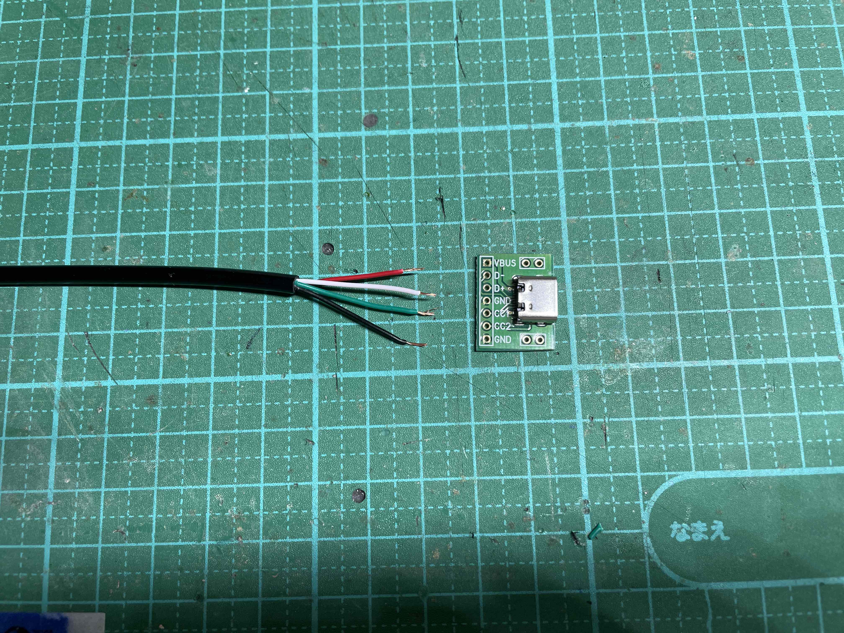
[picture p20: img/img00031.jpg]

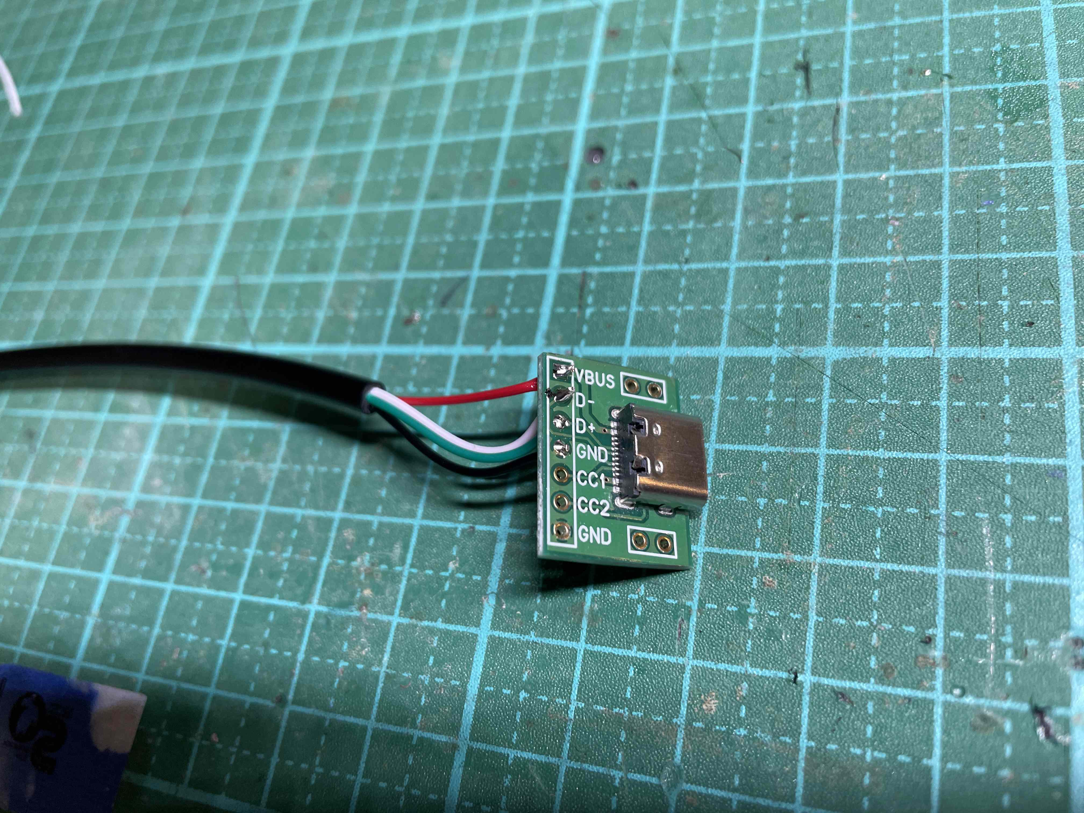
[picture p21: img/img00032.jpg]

次に、USBタイプC基板をPCBにハンダ付けで固定します。<br>
最初にピンヘッダをUSBタイプC基板側に取り付けてください。
次の画像を参考にしてください。
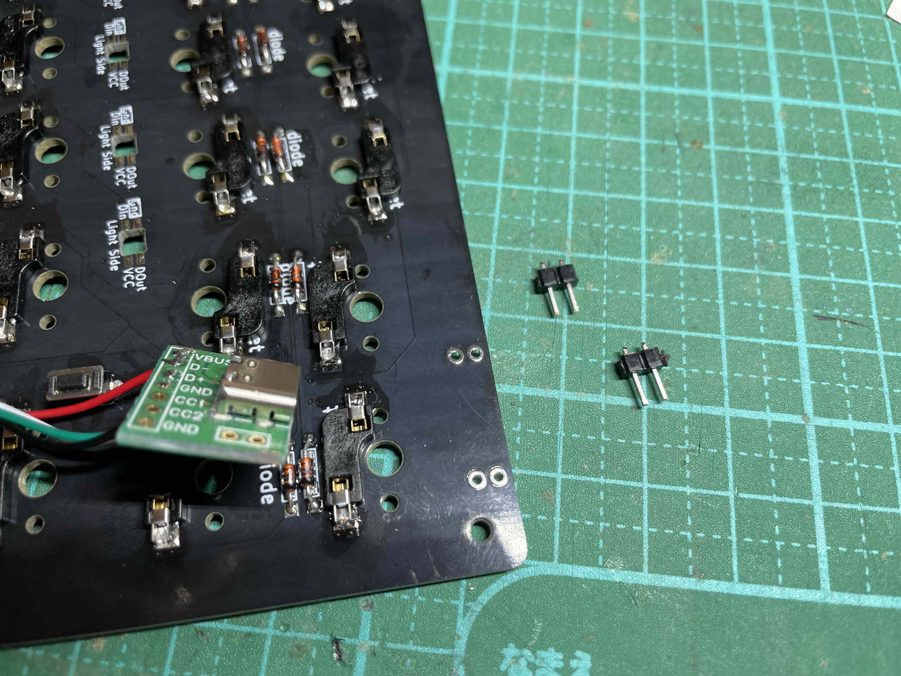
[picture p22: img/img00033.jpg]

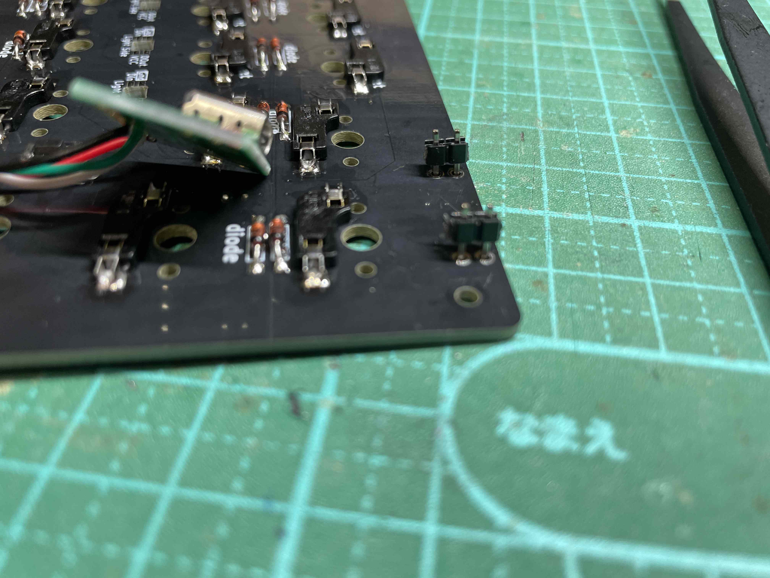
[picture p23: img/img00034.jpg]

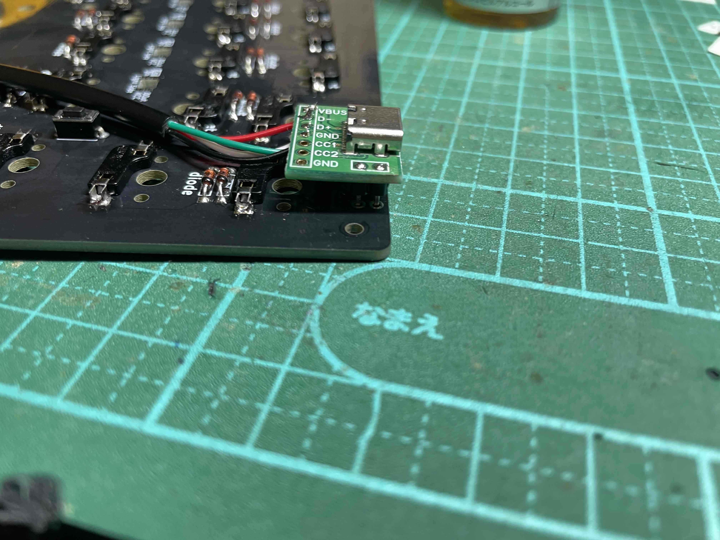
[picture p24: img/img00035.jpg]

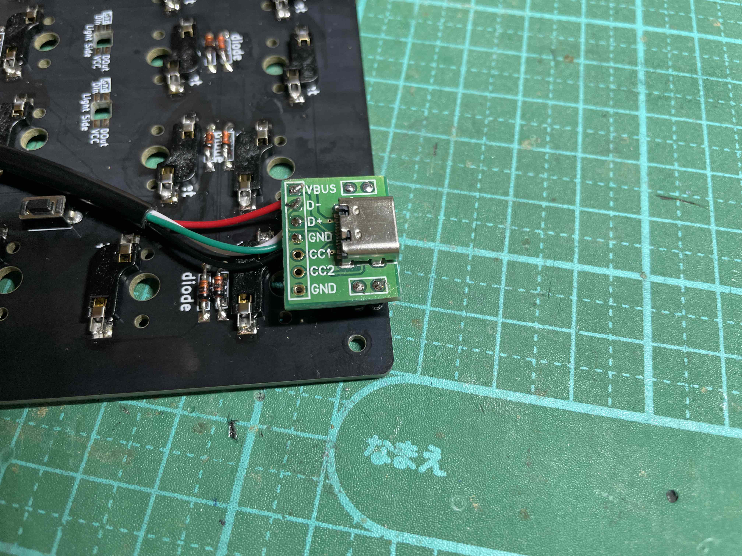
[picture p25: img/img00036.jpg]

次にPCB側にハンダ付けをしますが、その前に、
ミドルプレート下２枚、ボトムプレート大、ボトムプレート小１枚を
仮組みして、USBタイプC基板のハンダ付け位置を確認します。
この時、USBタイプC基板の個体差の関係で、幅が大きく、ミドルプレート下に干渉する場合、基板の両端部をヤスリで削ってください。<br>
次の画像を参考にしてください。

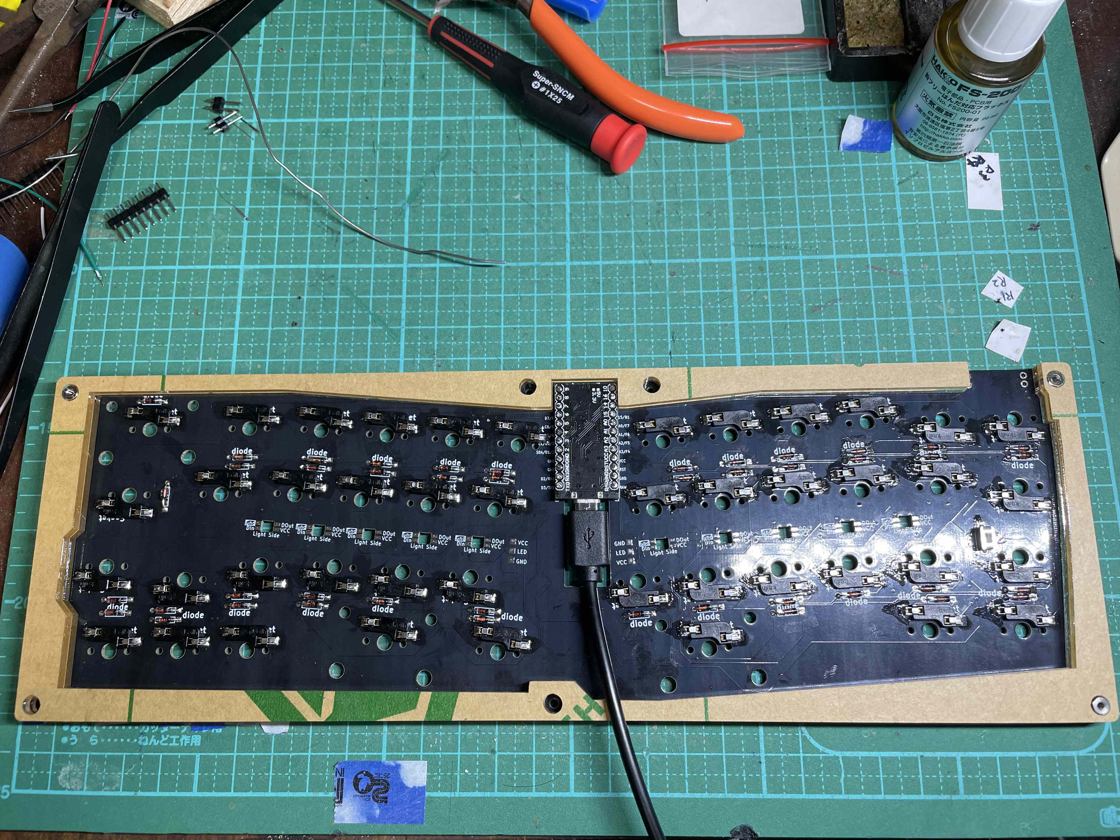
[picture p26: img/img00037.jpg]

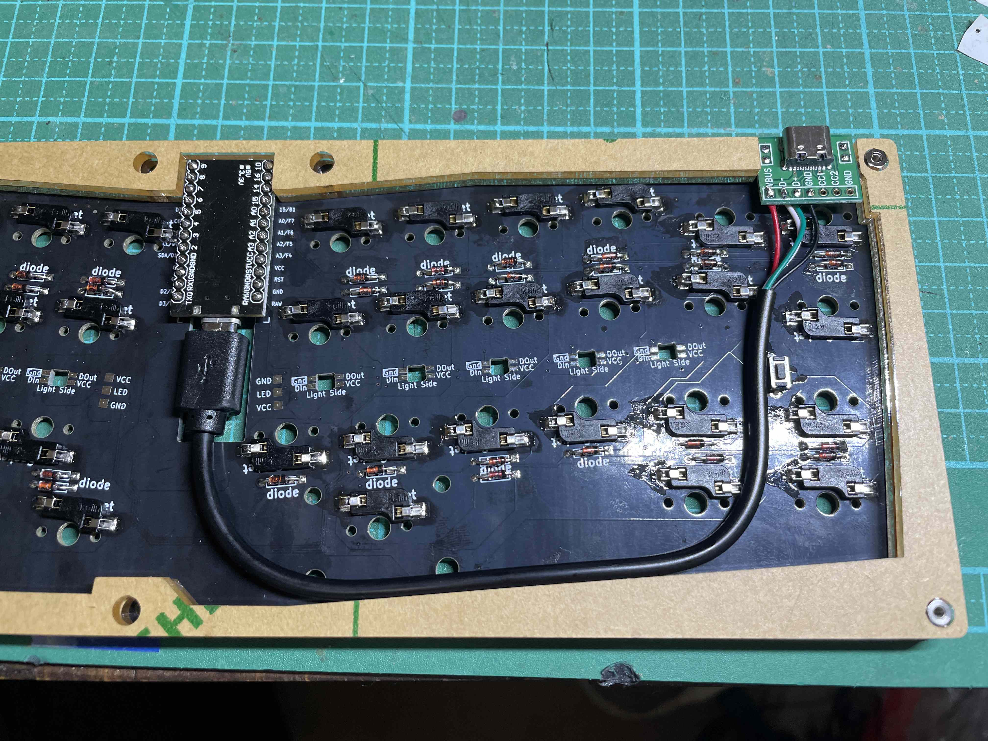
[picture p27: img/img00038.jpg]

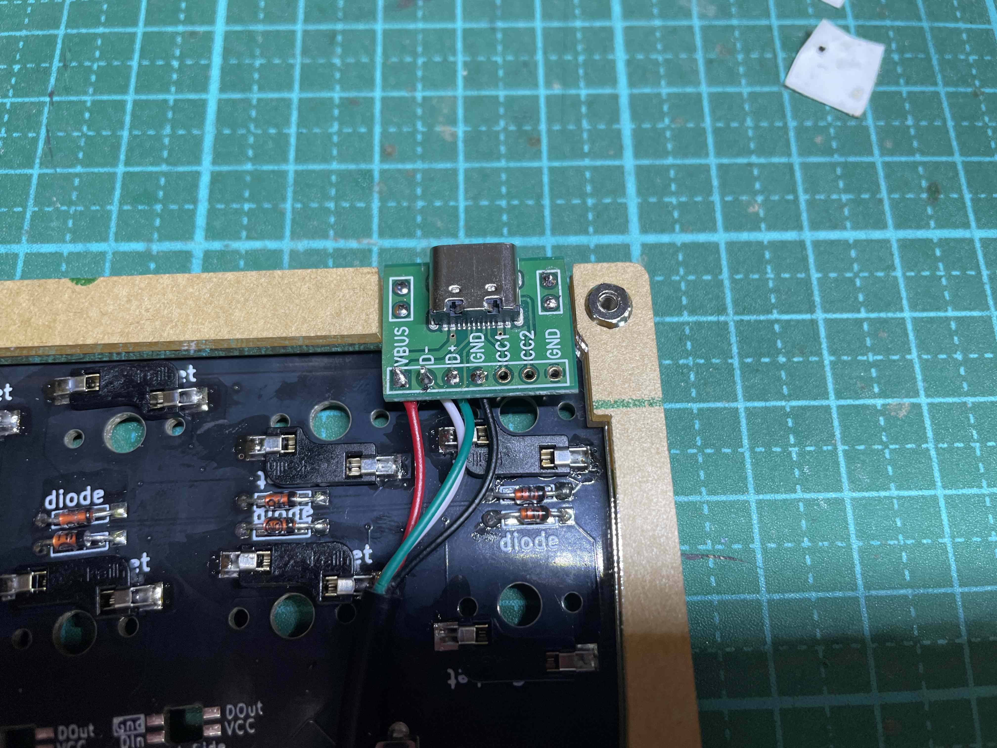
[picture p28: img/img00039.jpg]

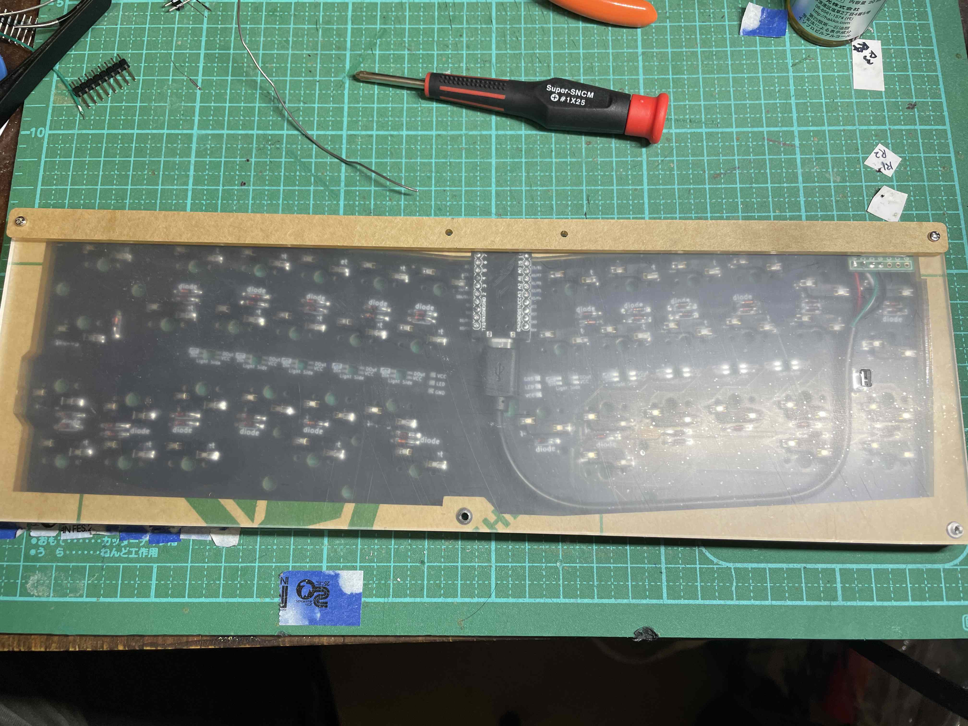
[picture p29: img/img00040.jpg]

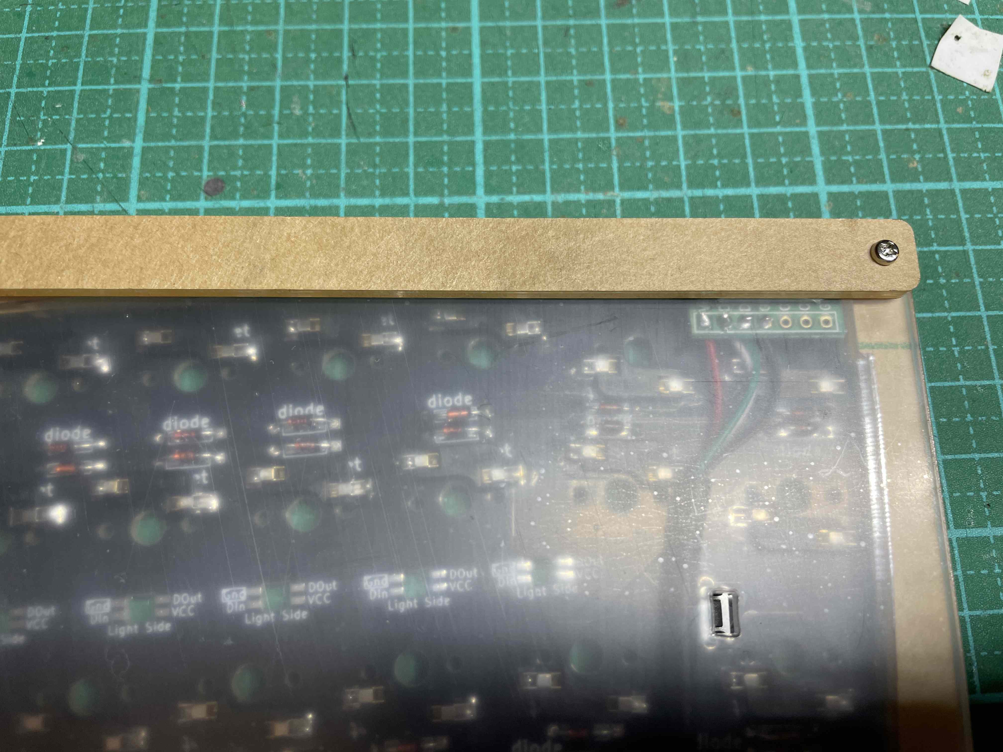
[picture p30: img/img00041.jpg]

下の画像のようにできたら、PCB側のハンダ付けをしてください。
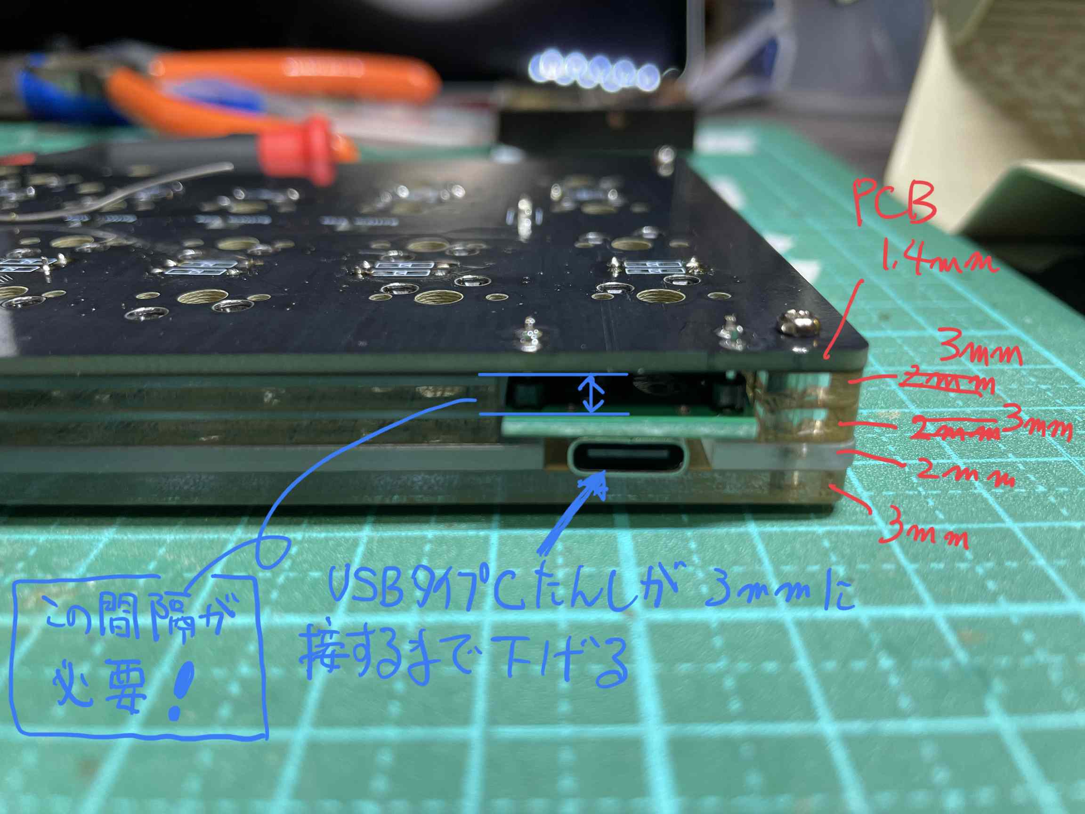
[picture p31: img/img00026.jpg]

ハンダ付けが終わったら、仮組みしたミドルプレート、ボトムプレート等を外してください。
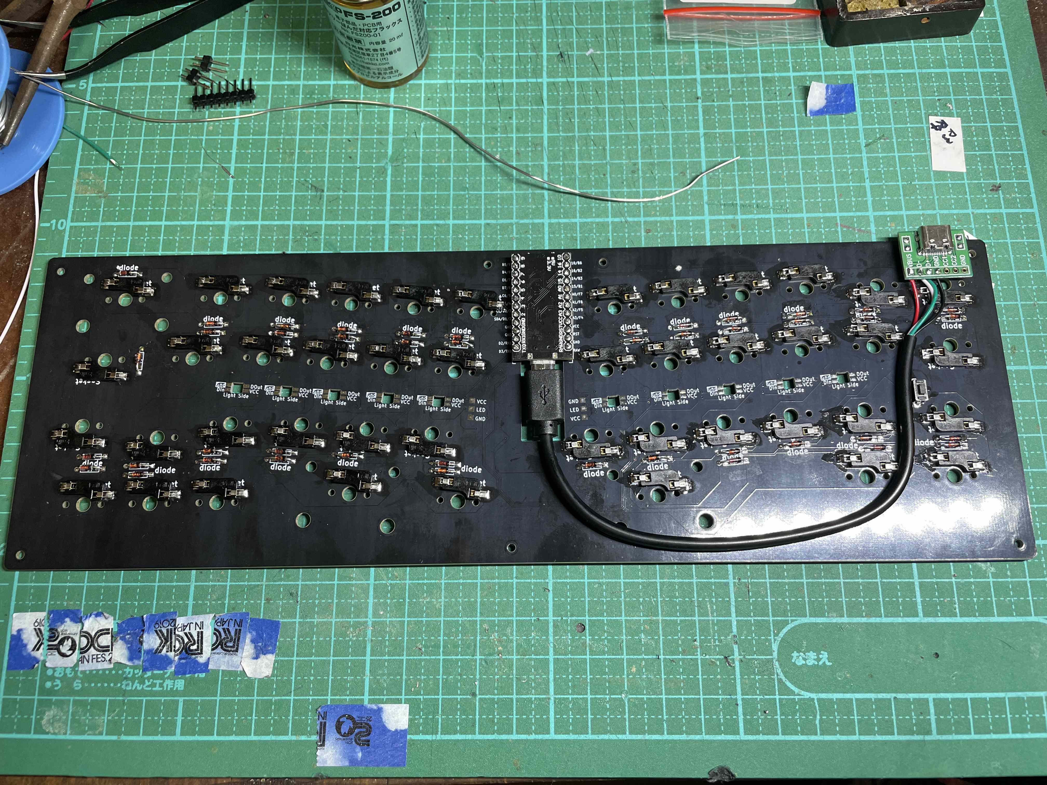
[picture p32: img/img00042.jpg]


# 7　スタビライザーの装着
PCB基板の上面にスタビライザー2Uサイズを３箇所を装着してください。<br>
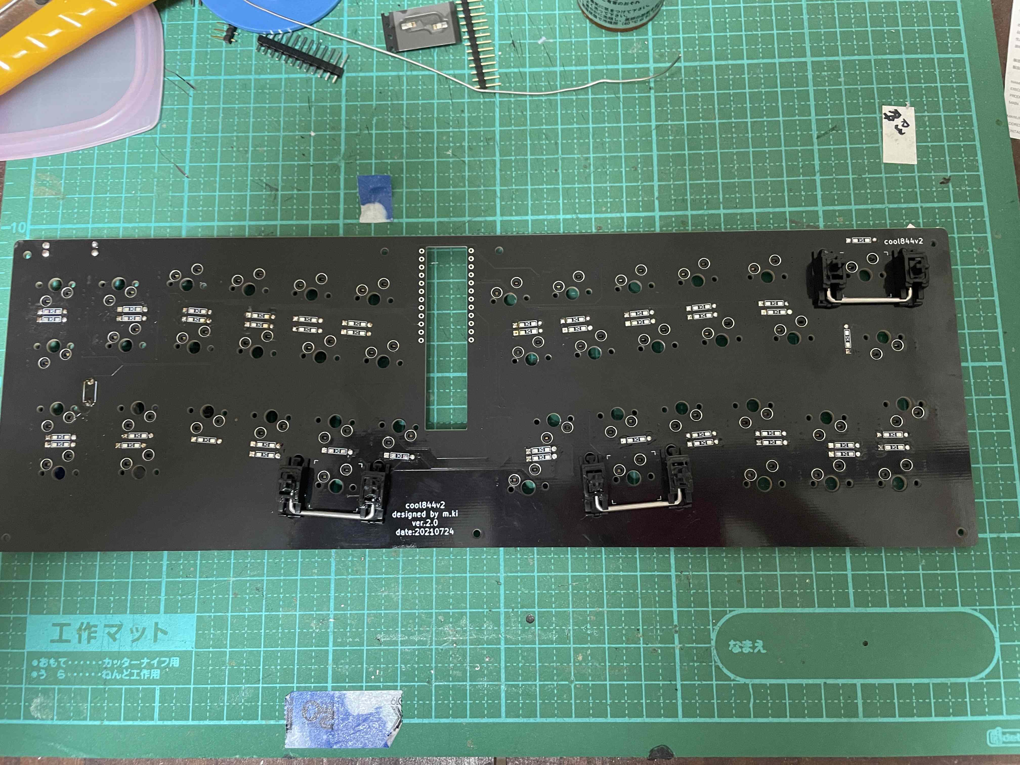
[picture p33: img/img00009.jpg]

<br>
# 8 スイッチプレート、ミドルプレート上の装着
PCBにミドルプレート上、スイッチプレートの順に重ねて装着します。<br>
注意　画像は豪華セット付属の透明のスイッチプレートです。
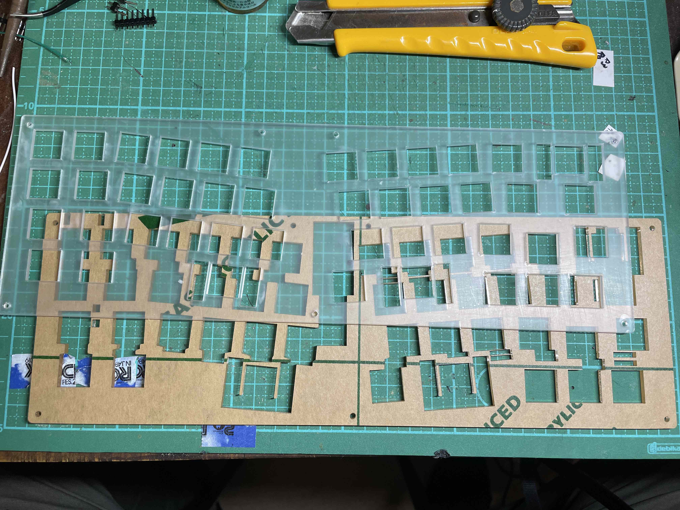
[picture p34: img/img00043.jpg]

アクリルの保護紙を外して使用してください。
アクリルには繊細な造形の部分もありますので、
保護紙を外すとき、ゆっくりと丁寧に行ってください。
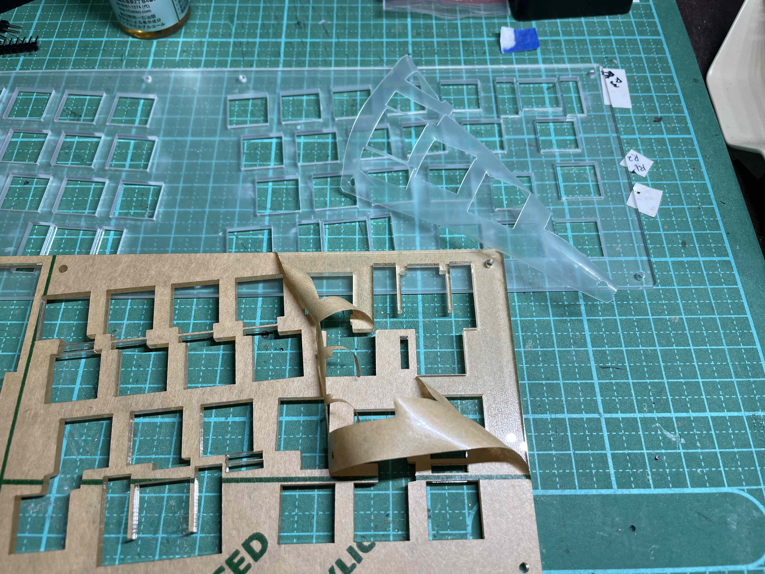
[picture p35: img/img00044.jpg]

PCBの上面にミドルプレート上１枚を重ねます。
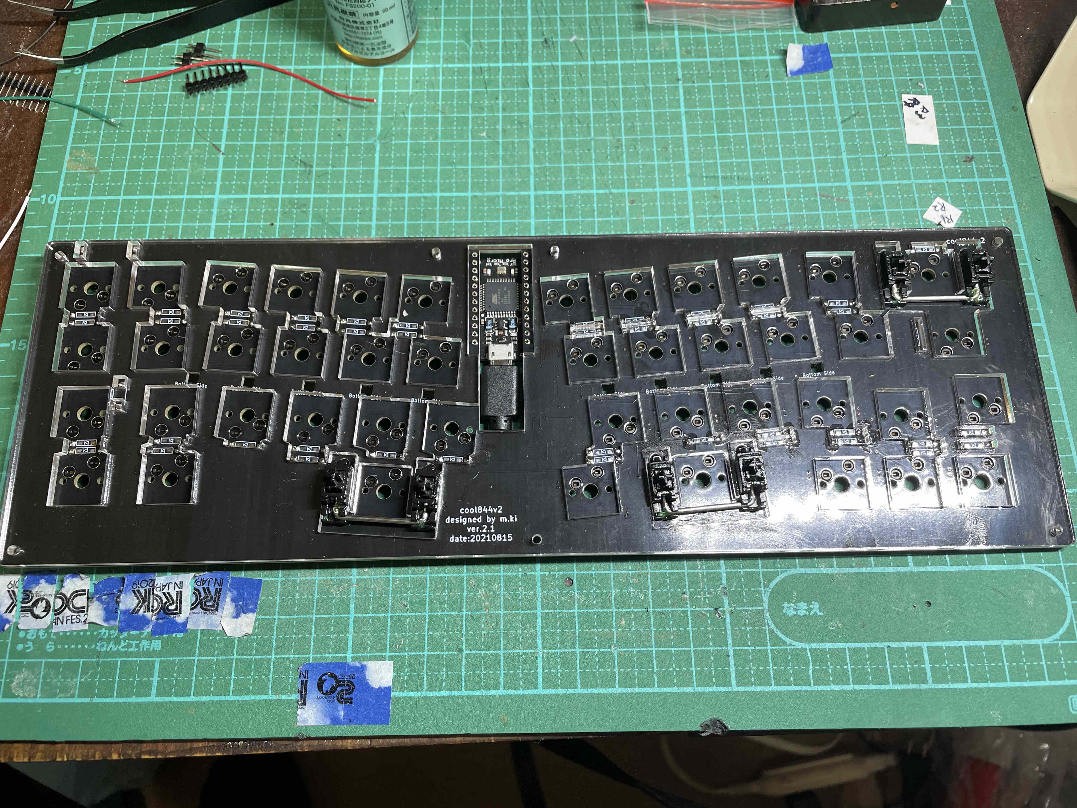
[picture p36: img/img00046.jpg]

さらに、スイッチプレートを１枚を重ねます。
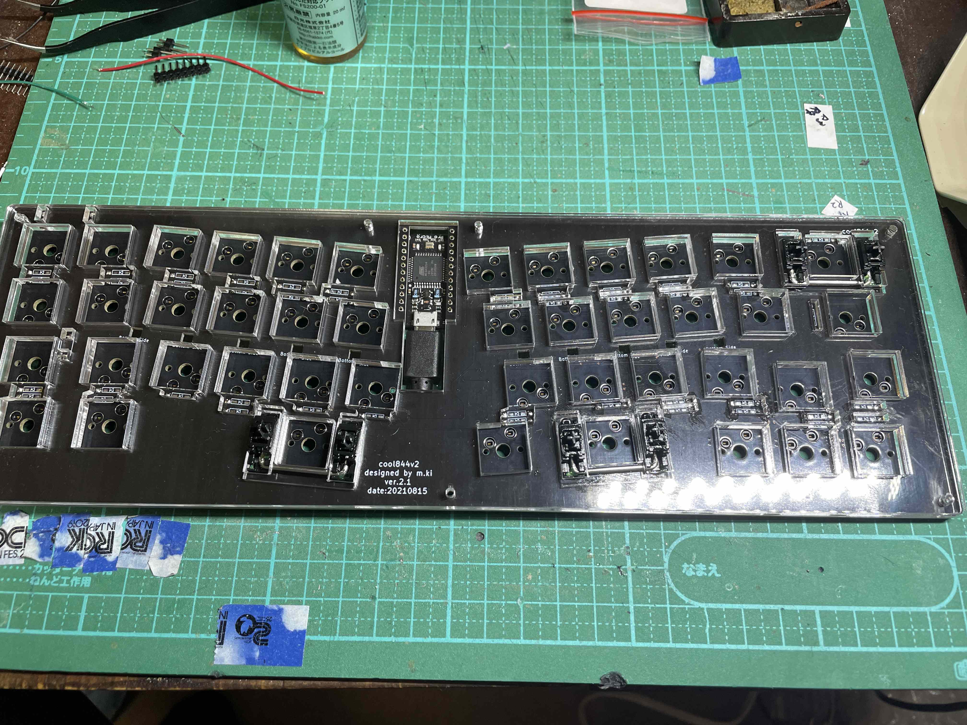
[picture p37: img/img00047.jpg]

次に、ネジやスペーサーで、スイッチプレートやミドルプレート上を
固定します。<br>
上からM2ネジ8mmをスイッチプレート側から差し込んで、PCB側にM2スペーサーで固定します。
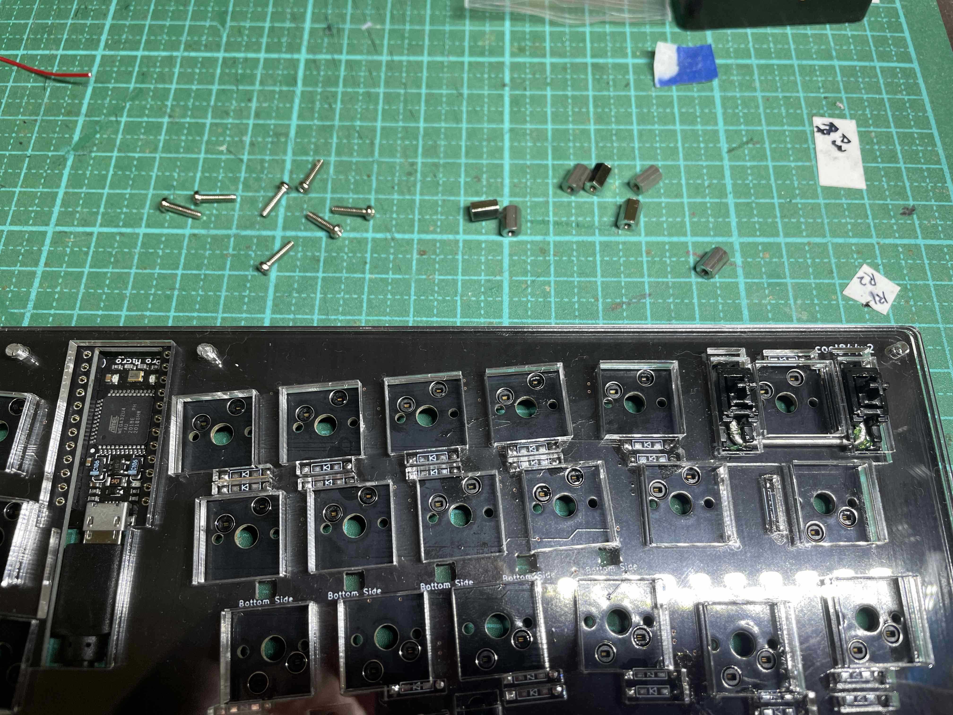
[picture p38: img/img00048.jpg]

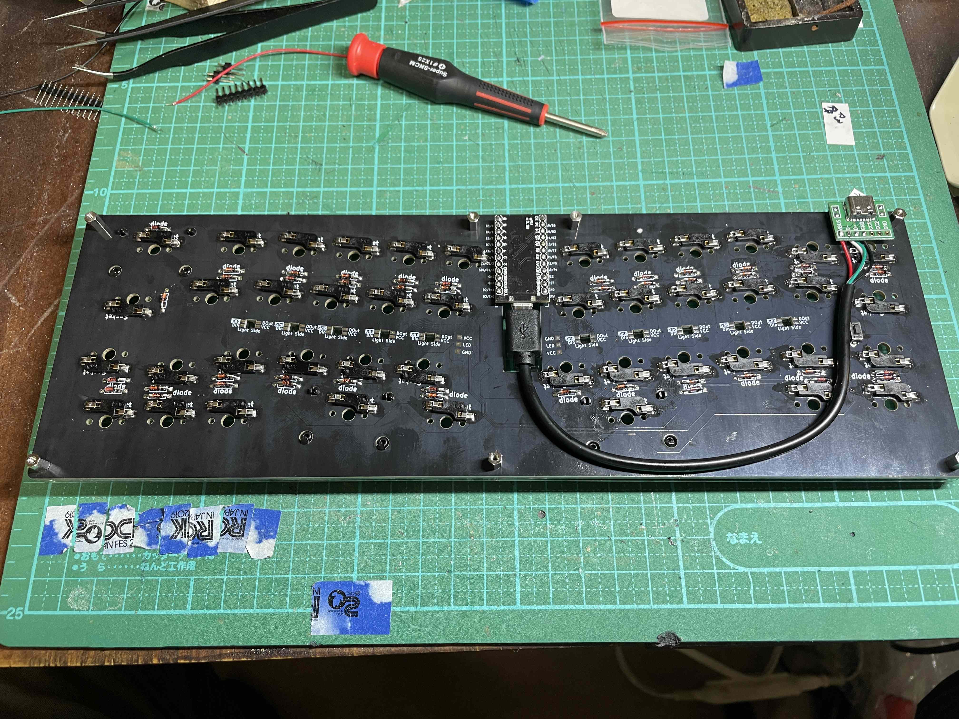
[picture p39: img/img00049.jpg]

<br>
# 9　キースイッチの装着
それぞれのキーソケットに、キースイッチを装着します。装着の際、キースイッチの端子が曲がってしまい、きちんとささらないことがあります。もし、入力できない時は、端子の確認を最初にしてください。それでも改善しないときは、キーソケットのハンダ付けが剥がれていることがあります。<br>
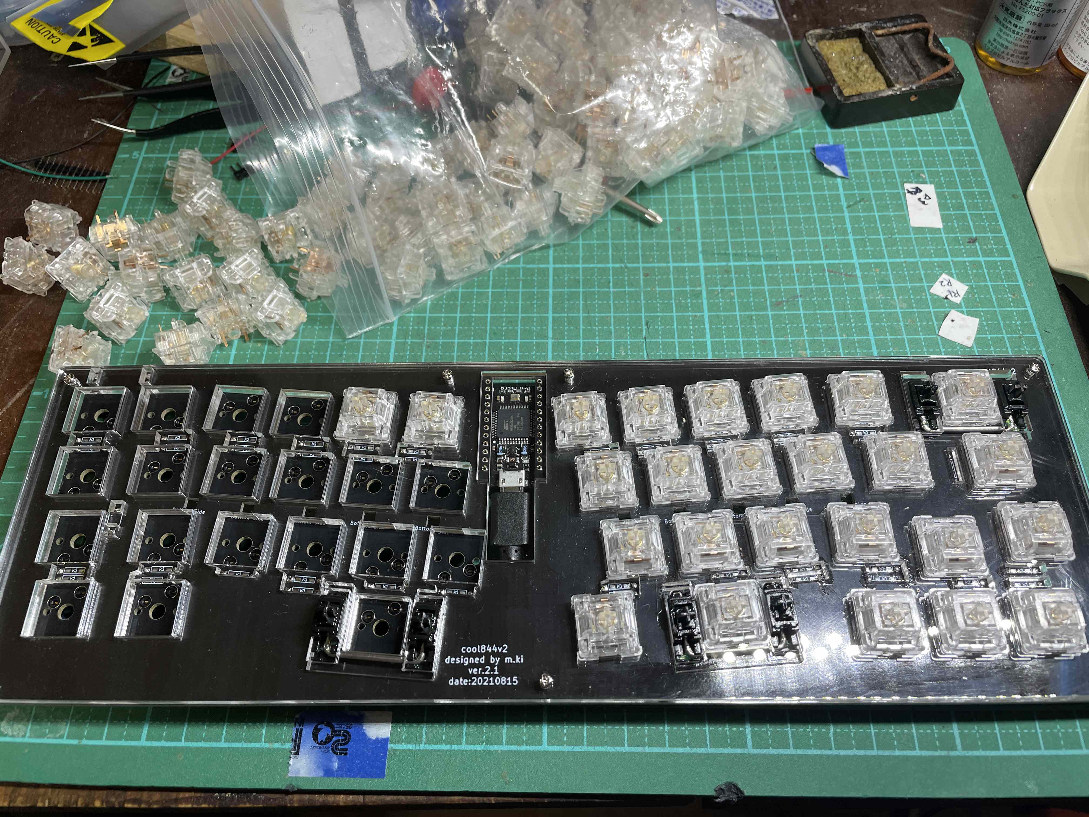
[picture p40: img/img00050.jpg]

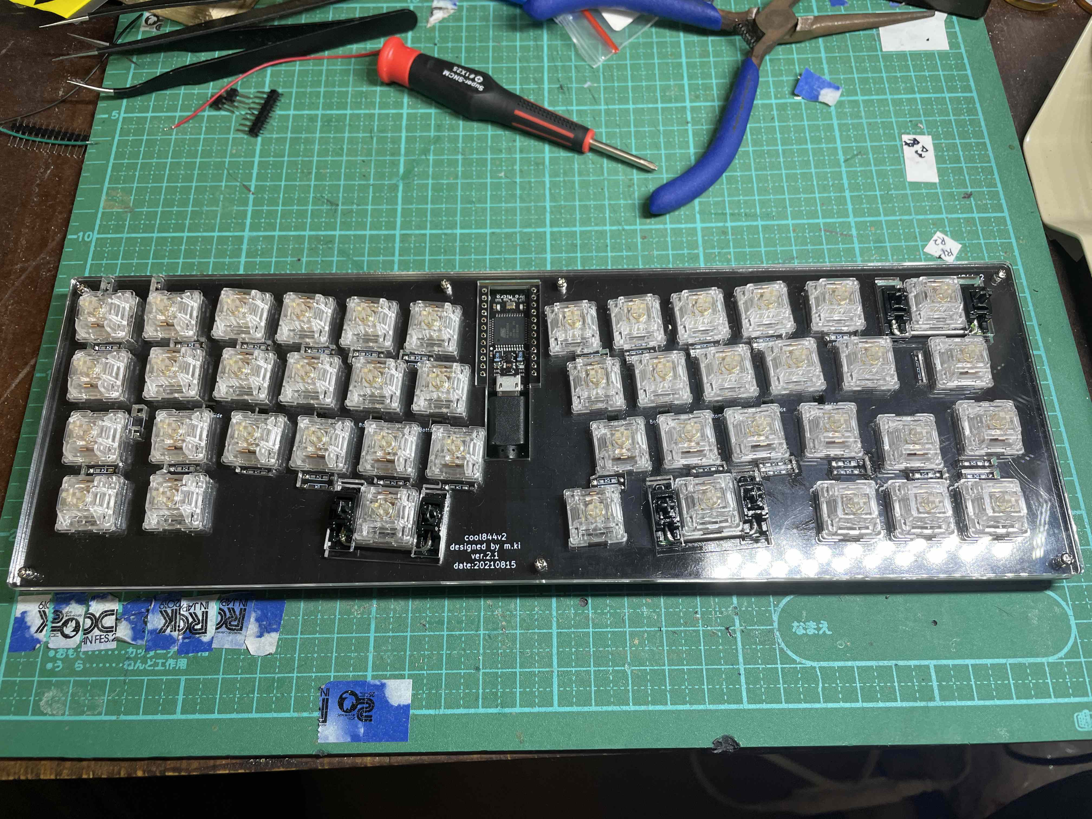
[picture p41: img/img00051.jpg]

<br>
# 10　ボトムプレート、ミドルプレート下２枚の装着
ミドルプレート下２枚を順に、PCBの下部に重ねます。
下の画像はミドルプレート下になります。保護紙を剥がしてください。
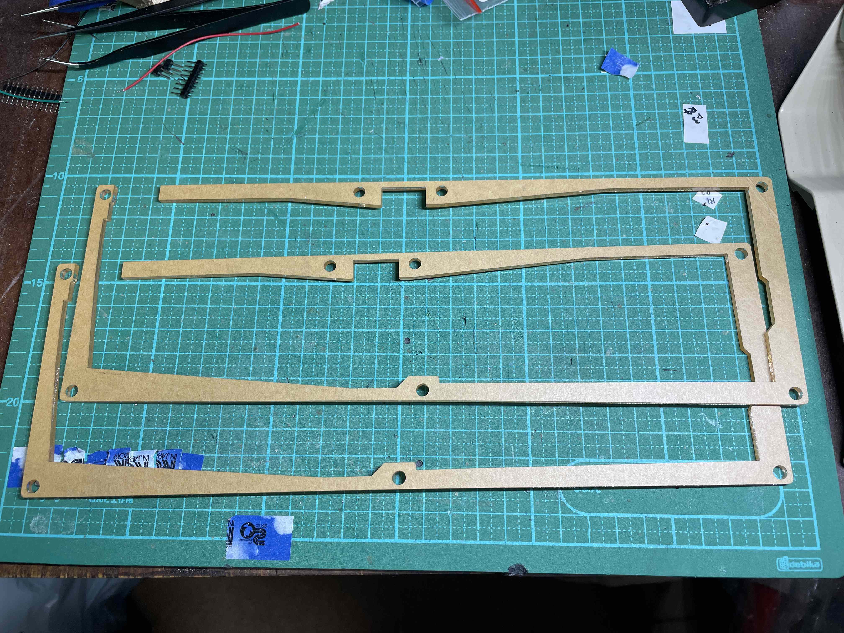
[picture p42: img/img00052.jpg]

重ねる際、USBタイプC端子付きケーブルが干渉しないように取り回してください。
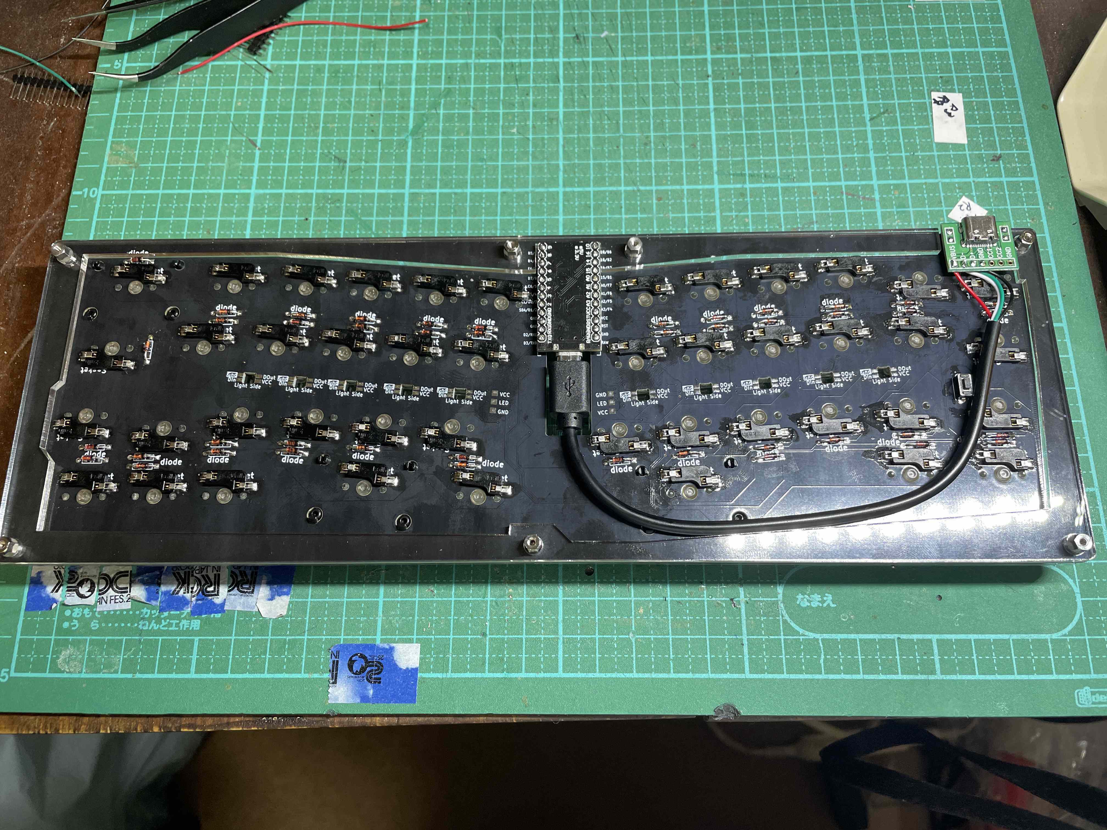
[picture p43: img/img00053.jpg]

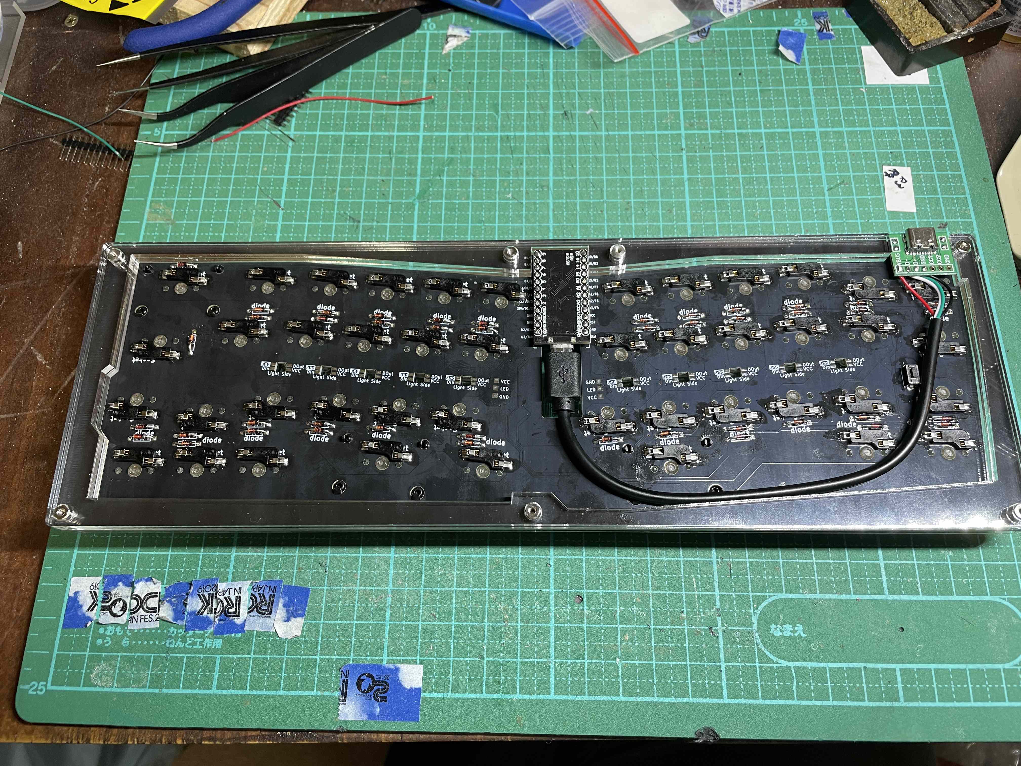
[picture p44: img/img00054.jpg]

アクリルの精度により、ミドルプレート下は２枚で6mm厚ですが、
6mmスペーサーでは、ややスペーサーの端部が出ています。<br>
できれば、5.5mmスペーサーが好ましいですが、5mmでも大丈夫です。5mmの場合は、上からのネジを先に締めることを意識してださい。<br>
ミドルプレート下２枚重ねた上に、ボトムプレート大を重ねて、３箇所だけ、M2ネジ4mmでねじ締めをします。
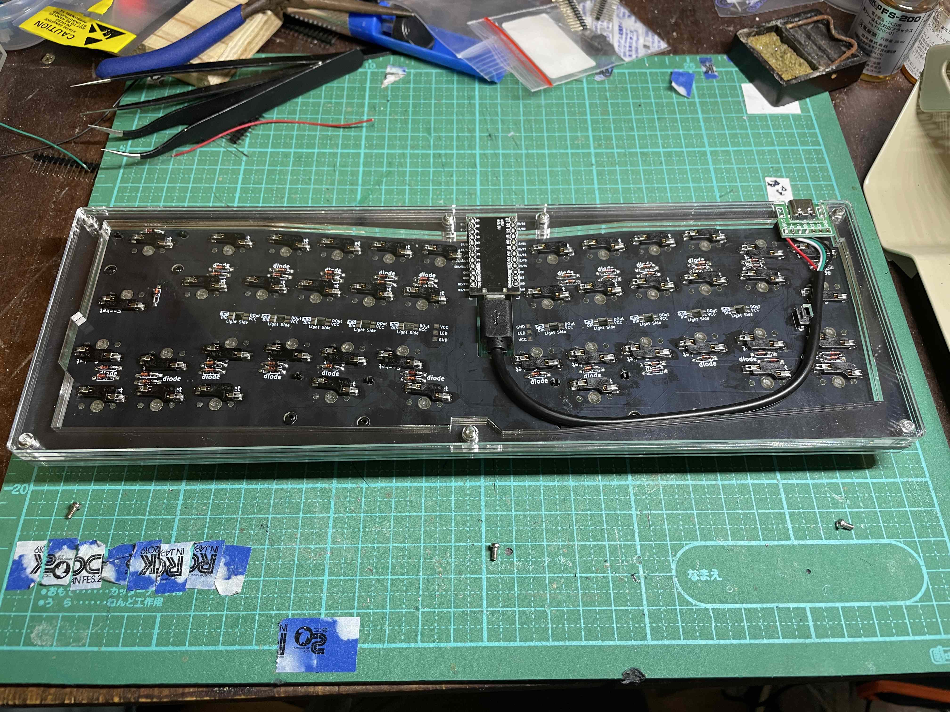
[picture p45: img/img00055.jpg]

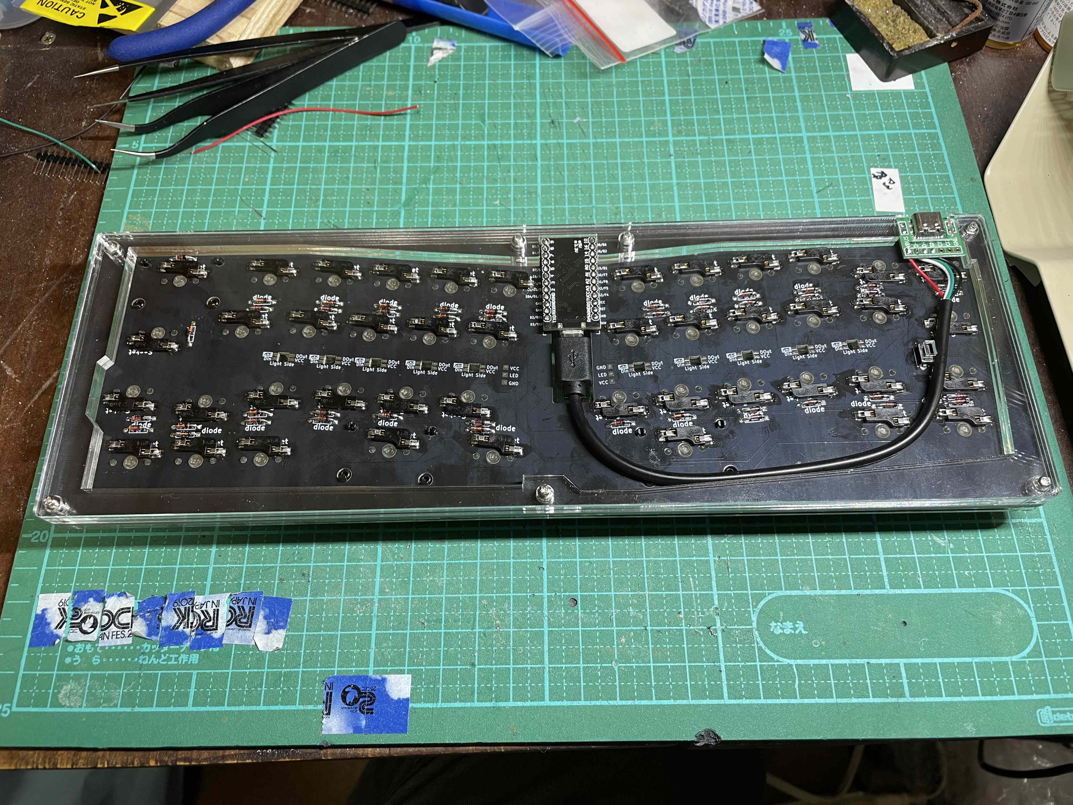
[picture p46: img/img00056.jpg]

次に、ボトムプレート小を３枚重ねて、M2ネジ12mmでねじ締めします。
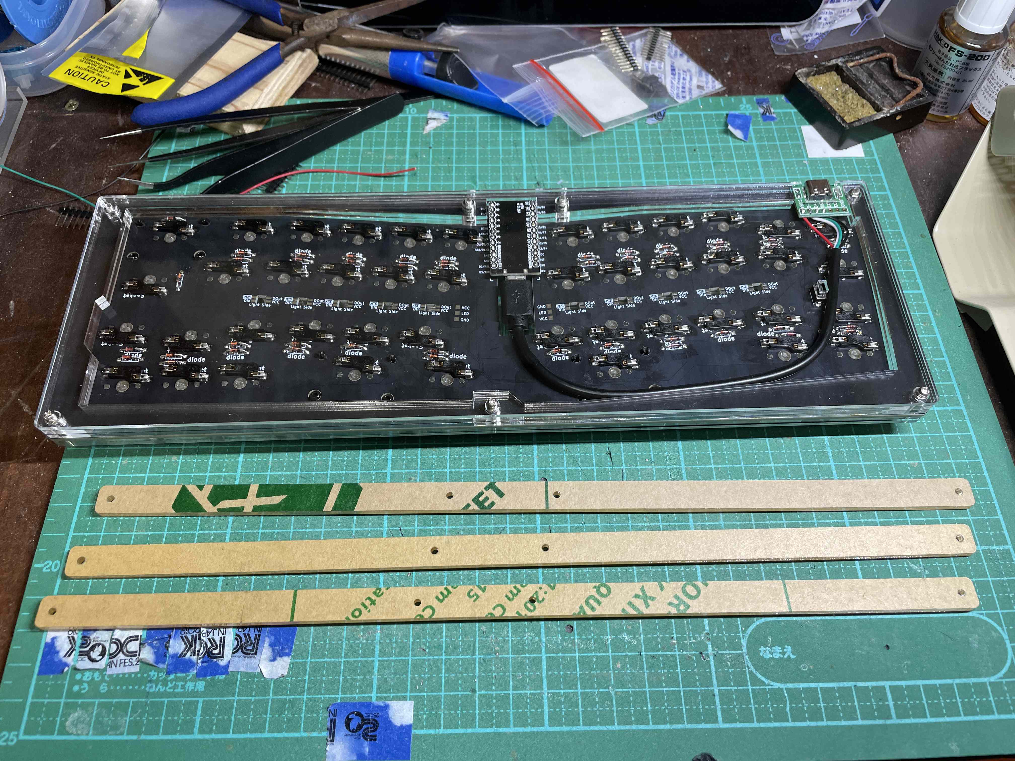
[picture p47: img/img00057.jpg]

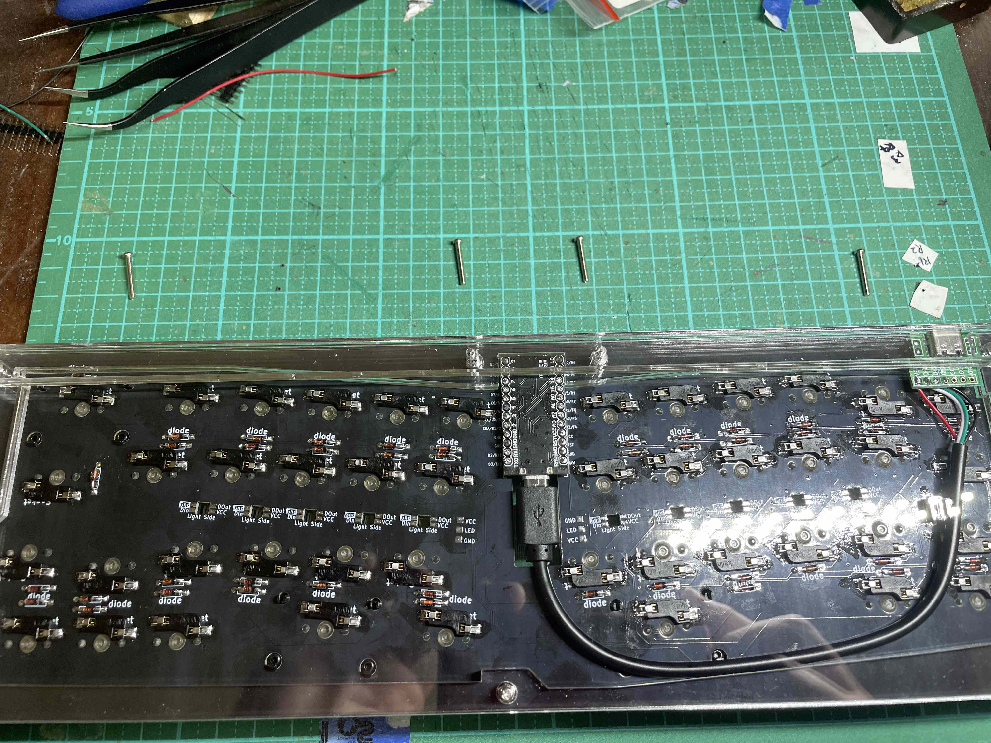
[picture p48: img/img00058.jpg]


この後、任意でゴム足をボトムプレートに装着すると、滑りにくくなります。<br>

<br>
# 11　キーキャップの装着
お気に入りのキーキャップを装着して完成です。<br>


注意　上の画像は豪華セットに付属している透明のスイッチプレートでの作成例です。
基本セットには黒色のスイッチプレートとなり、キーボード上面から、pro microを
見ることはありません。
<br>

# 12　ファームウェア
cool844と同じものが使えます。<br>
[REMAP](https://remap-keys.app/configure)に対応しています。
[REMAP](https://remap-keys.app/configure)ではcool844と表示されますが、問題ありません。<br>
[Yoichiro Tanaka@yoichiro](https://twitter.com/yoichiro)さん等が開発した[REMAP](https://remap-keys.app/)が使用できます。
<br>

**ファームウェアの書き込み**
<br>
pro microとPCをUSBケーブルで繋ぎ、google chromeで[REMAP](https://remap-keys.app/)サイトへアクセスしてください。<br>



画面中央の「KEYBOARD CATALOG」をクリックしてください。<br>
画面が変わりましたら、左上の「Keyboard Name」に「cool」と
入力して、下部の「SEARCH」をクリックしてください。
<br>
coolシリーズのキーボードが表示されます。

この中から、該当するキーボードを選び、クリックしてください。
<br>
例えば、cool844であれば、次の画面に変わります。
そこでタブの「FIRMWARE」をクリックすると、

このように、via用hexファイルが表示されます。
「FLASH」をクリックすると、

Flash Firmwareが起動して、pro microへの書き込みができます。
<br>
以上で、pro microへのファームウェアの書き込みは完了です。
<br>
<br>
**キーレイアウトの編集**
<br>
google chromeが動くパソコンとcool847をUSBケーブルでつなぎます。<br>
そのあと、[REMAP](https://remap-keys.app/configure)にアクセスして、 


画面中央の「＋KEYBOARD」をクリックしてください。<br>
<br>

キーボードとパソコンが繋がっていれば、次のような表示でます。

cool844を選び、「接続」をクリックしてください。<br>



そうすると、REMAPのサイト上で、cool844のキーレイアウトを編集することができます。

REMAPのおかげで、自作キーボードのファームウェアの書き込み、キーレイアウトの変更が大変、簡単になりました。
<br>

# 13　60%汎用ケースへの換装
ケースはcool844と同じように、GH60系60％キーボードケースを使うことが前提になっています。
国内では遊舎工房やTalp Keyboard等で、海外ではAli Expresse等で同じようなケースを材質ごとに、見つけることができます。
cool844V2がケース全てに使えるか確認することは、個人の裁量を超えます。購入者の自己責任でお願いします。<br>
令和３年９月18日時点では、私個人で所有している５つのケースでの使用を確認しています。<br>
ただし、ケースごとに若干個体差があるようで、端子挿入口の高さや、
本体内部のねじ穴位置が少し違います。<br>
その際は、ゲタのネジでの固定位置を減らすことや、USBタイプC基板の設置する高さの修正をしてください。<br>
または、ネジ穴を拡張して対応する等、個々の対応となります。<br>
次の換装例では、ネジ穴の拡張をせず、固定するネジを減らしまして対応しましたが、使用上、問題はなかったです。
## 換装例１ 木製ケース（Talp　Keyboardで購入）　



## 換装例２　プラスチックケース（遊舎工房で購入）



## 換装例３　TOFUケース（遊舎工房で購入）




## 換装例４　MelGeek Mojo60ケース（Talp Keyboardで購入）



## 換装例4　Light Edgeケース（Talp Keyboardで購入）


## 換装方法
ゲタと名付けたアクリルプレートのねじ穴７箇所に
M2ネジ４mmでM2スペーサー3mmを固定します。<br>
場所を下の画像を参考にしてください。

この後、ゲタを汎用ケース内に置き、M2ネジ3mmで固定します。<br>
その前に、一度、cool844V2は、その上部のネジを緩めて、上下に分けてください。<br>
上部はスイッチプレート、ミドルプレート上、PCBで構成されています。上部を、先程作ったゲタに合わせてください。
この作業は、PCB下部を這っているUSBタイプC端子付きケーブルがゲタの固定を邪魔していないか確認するためのものです。
邪魔するようであれば、ケーブルの取り回しを調整してください。
また、ケーブルとスイッチソケットが重なっていると、ゲタが上手に固定できない問題があります。
ケーブルを取り回す際、勢い余って、pro microの端子に負荷をかけて、もげないよう注意してください。
<br>
ゲタの装着に問題ないことが確認できましたら、ゲタを一旦外して、汎用ケース内に戻して、ネジで固定してください。<br>

ネジの固定ができましたら、上部を汎用ケースに乗せて、上部にあるネジ７箇所で固定してください。
<br>完成です。<br>


# 14　LEDについて
任意で、LEDを装着して光らせることができます。<br>
cool844V2は、
LEDテープ（フルカラーシリアルLEDテープ）または、SK6812MINI-Eに対応しています。<br>
ハンダ付けに自信がない人は、LEDテープをお勧めします。<br>
PCB裏面に中央部にLEDテープを装着するため、GND、VCC、LEDの端子があります。
LEDテープは、テープの端子と、その端子をつなぐように、ハンダ付けしてください。<br>
SK6812MINI-Eは、必要個数10を、中央から左右に広がる四角形の枠に納めていって、それぞれハンダ付けをしてください。<br>
SK6812MINI-Eをハンダ付けする際は、コテの温度を220℃ほどで行ってください。温度が高いと、破損する恐れがあります。<br>
LEDの装着は、アクリル積層密閉型ケース（スタンドアローン版）か、60％汎用ケースが透過される透明なものでないかぎり、効果ありません。<br>

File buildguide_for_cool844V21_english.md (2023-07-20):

# cool844V2 buildguide（ver.2.1対応)

※This is a translation of the Japanese version of the build guide using DeepL or Google Translater, so the wording may not be appropriate.

### <Features>
cool844V2 (ver.2.1) is a self-made keyboard designed by m.ki.
<br>
To use it in a generic case for a 60% homemade keyboard,
It is the same as the previous cool844.
It can also be used by itself without being housed in a general-purpose case,
The acrylic bottom plate and other accessories are included in the package.
Depending on the mood of the day, it can be used in a general-purpose case of your choice,
You can use it in your favorite general-purpose case or in a sealed case made of acrylic laminate, depending on your mood.
<br>

cool844V2　Acrylic laminate sealed case

cool844V2　Optional 60% general purpose case (with wooden case)

cool844V2　Before case storage

NOTE <br>
The transparent switch plate used in the finished image above is the one enclosed in the luxury set.
In the basic set, the switch plate is black, giving a subdued look.
<br>
<br>
# 0　reference
cool844V2 is basically the same as cool844. If you have trouble assembling, please refer to the cool844 [Build Guide](https://github.com/telzo2000/cool844/blob/main/buildguideforcool844.md).<br>
Be sure to read the instructions before assembling.
<br>

# 1　Parts Identification
This product includes a switch plate, middle plate (2 types, 3 pieces), PCB, large bottom plate, small bottom plate (3 pieces),
1 acrylic plate for "geta" conversion,
It consists of a cable with micro USB terminal (male), 7 M2 spacers 5.5 mm, 7 M2 screws 8 mm, 3 M2 screws 4 mm, and 4 M2 screws 12 mm.。<br>
<br>
The following items are to be provided by you
44 diodes, 44 switch sockets, 1 reset switch, 1 pro micro, 2 spring pin headers (Mac Eight con through), 3 stabilizers 2U, 1 USB type C board, and your favorite keycap set.
When converting to a 60% general purpose case, 7 M2 spacers 3mm and 12 M2 screws 4mm will be required.
<br>

<br>

# 2　Soldering of diodes
On the bottom side of the PCB board (the side with "cool844V2" printed on the right corner of the board is the top side), "diode" is printed. Insert the PCB from the printed side and solder from the top side. Solder carefully in the right direction.<br>


<br>

# 3　Soldering of switch sockets
Socket" is printed on the underside of the PCB board. Place the switch socket so that the printing is not visible, and solder it in place. The switch socket has an orientation. If the orientation is wrong, the key switch will not turn on.
<br>
When placed in the correct orientation

If placed in the wrong orientation ("Socket" print is visible)
間違った向き
<br>
# 4　Reset switch soldering
RESET" is printed on the underside of the PCB. Place the reset switch on the PCB and solder it from the top surface so that the printing is not visible.<br>
<br>
# ５　Soldering pro micro
Insert two spring pin headers into the underside of the PCB.
The spring headers have small holes on their sides.
The direction of the holes must be aligned.

Insert the pro micro into the spring pin header and solder the pro micro to the spring pin header.
Note the orientation of the pro micro.<br>


<br>
# ６ Daughter Board Creation
Cut the supplied cable with micro USB terminal (male) to the required length.<br>

First, cut about 19 cm from the terminal side.
After that, leave about 16 cm of black film and about 3 cm beyond that. <br>
Peel off the film of the cable divided into four colors and solder each to the terminal of the USB type C board.
Connect red to VBUS, white to D-, green to D+, and black to GND.


Then solder the USB type C board to the PCB. <br>
Please attach the pin header to the USB type C board side first.
Please refer to the following image.




Next, solder to the PCB side, but before that,
2 lower middle plates, large bottom plate, 1 small bottom plate
Temporarily assemble and check the soldering position of the USB type C board.
At this time, due to individual differences in the USB type C board, if the width is large and interferes under the middle plate, file both ends of the board. <br>
Please refer to the following image.






If you can do it like the image below, please solder the PCB side.

After soldering, remove the temporarily assembled middle plate and bottom plate.


# 7　Attaching the stabilizer
Attach 3 stabilizers of 2U size to the top of the PCB board.<br>

<br>

# 8 Installation on switch plate and middle plate
Mount the middle plate on the PCB, then the switch plate, in that order. <br>
Note: The image is the transparent switch plate that comes with the deluxe set.

Remove the acrylic protective paper before use.
Since acrylic has delicate molding parts,
Be slow and gentle when removing the protective paper.

PCBの上面にミドルプレート上１枚を重ねます。
Place one middle plate on top of the PCB.

In addition, stack one switch plate.

Next, use screws or spacers to secure the switch plate and middle plate.
Fixed. <br>
Insert the M2 screw 8mm from the top from the switch plate side and fix it to the PCB side with the M2 spacer.


<br>

# 9 Installation of key switch
Attach a key switch to each key socket. When installing, the terminal of the key switch may be bent and may not fit properly. If you cannot input, please check the terminal first. If it still doesn't work, the solder on the key socket may be peeling off. <br>


<br>

# 10 Installation of bottom plate and middle plate
Place the bottom two middle plates in order on the bottom of the PCB.
The image below is under the middle plate. Please peel off the protective paper.

When stacking, arrange the cables so that the cables with USB type C terminals do not interfere.


Due to the accuracy of the acrylic, the thickness of the two under the middle plate is 6mm,
With a 6mm spacer, the edge of the spacer protrudes slightly. <br>
If possible, 5.5mm spacers are preferable, but 5mm is fine. For 5mm, remember to tighten the screws from the top first. <br>
Overlap the bottom plate on top of the two lower middle plates, and tighten only 3 places with 4mm M2 screws.


Next, stack 3 small bottom plates and tighten them with M2 screws 12mm.



After this, optionally attach rubber feet to the bottom plate to prevent slippage. <br>

<br>
# 11 Mounting the key cap
Complete with your favorite keycap. <br>


Note: The image above is an example of using the transparent switch plate that comes with the deluxe set.
The basic set has a black switch plate, and you can connect the pro micro from the top of the keyboard.
never see.
<br>

# 12 Firmware
You can use the same one as cool844. <br>
[REMAP](https://remap-keys.app/configure) is supported.
[REMAP](https://remap-keys.app/configure) shows it as cool844, which is fine. <br>
You can use [REMAP](https://remap-keys.app/) developed by [Yoichiro Tanaka@yoichiro](https://twitter.com/yoichiro).
<br>
<br>

**Firmware Burn**
<br>
Connect the pro micro and PC with a USB cable, and access the [REMAP](https://remap-keys.app/) site with google chrome. <br>



Click "KEYBOARD CATALOG" in the center of the screen. <br>
When the screen changes, put "cool" in "Keyboard Name" on the upper left
Please enter and click "SEARCH" at the bottom.
<br>
Cool series keyboard will appear.

From this list, select the appropriate keyboard and click on it.
<br>
For example, if it is cool844, it will change to the following screen.
Then click the "FIRMWARE" tab,

In this way, the hex file for via is displayed.
Click "FLASH"

Flash Firmware will start and you can write to the pro micro.
<br>
This completes writing the firmware to the pro micro.
<br>
<br>

**Edit Key Layout**
<br>
Connect a computer running google chrome and cool847 with a USB cable. <br>
After that, access [REMAP](https://remap-keys.app/configure),


Click "+KEYBOARD" in the center of the screen. <br>
<br>

If the keyboard is connected to the computer, the following display will appear.

Select cool844 and click "Connect". <br>



Then you can edit the cool844 key layout on the REMAP site.

Thanks to REMAP, writing the firmware for your own keyboard and changing the key layout has become very easy.
<br>

# 13 Converting to 60% general-purpose case
Like the cool844, the case is based on the assumption that a GH60 series 60% keyboard case will be used.
You can find similar cases by material at Yusha Kobo, Talp Keyboard, etc. in Japan, and at Ali Expresse, etc. overseas.
Making sure the cool844V2 works for all cases is beyond personal discretion. Buyer's own responsibility, please. <br>
As of September 18, 2021, I have confirmed its use in five cases that I personally own. <br>
However, there seems to be some individual differences for each case, the height of the terminal insertion port,
The screw hole position inside the main body is slightly different. <br>
In that case, please reduce the fixing position with the screw of the geta and correct the height at which the USB type C board is installed. <br>
Alternatively, it will be handled individually, such as by expanding the screw hole. <br>
In the following conversion example, we did not expand the screw holes and reduced the number of fixing screws, but there was no problem in use.

## Conversion example 1 Wooden case (purchased at Talp Keyboard)　



## Conversion example 2 Plastic case (purchased at Yusha Kobo)



## Conversion example 3 TOFU case (purchased at Yusha Kobo)




## Conversion example 4 MelGeek Mojo60 case (purchased from Talp Keyboard)



## Conversion example 4 Light Edge case (purchased from Talp Keyboard)


## How to convert
In seven screw holes of the acrylic plate named geta
Fix M2 spacer 3mm with M2 screw 4mm. <br>
Please refer to the image below for the location.

After this, put the geta in the general-purpose case and fix it with M2 screws 3mm. <br>
Before that, once cool844V2 loosen the screw on its top and separate it into upper and lower parts. <br>
The top consists of a switch plate, a middle plate, and a PCB. Align the top with the geta you made earlier.
This work is to check if the cable with USB type C terminal crawling on the bottom of the PCB does not interfere with the fixation of the geta.
Adjust the routing of the cables if they are in the way.
Also, if the cable and switch socket overlap, there is a problem that the geta cannot be fixed well.
When routing the cable, be careful not to overload the terminal of the pro micro and break it.
<br>
Once you have confirmed that there is no problem with the fitting of the geta, remove the geta once, put it back in the general-purpose case, and fix it with screws. <br>

After fixing the screws, place the upper part on the general-purpose case and fix it with the 7 screws on the upper part.
<br>Completed. <br>


# 14 About LEDs
Optionally, you can attach an LED to make it glow. <br>
The cool844V2 is
Compatible with LED tape (full color serial LED tape) or SK6812MINI-E. <br>
If you are not confident about soldering, we recommend LED tape. <br>
There are GND, VCC, and LED terminals for mounting the LED tape in the center on the back of the PCB.
Solder the LED tape so that it connects the terminal of the tape to the terminal of the tape. <br>
For the SK6812MINI-E, place the required number of 10 in the square frame that spreads left and right from the center and solder each. <br>
When soldering the SK6812MINI-E, please keep the temperature of the soldering iron at about 220°C. High temperatures may cause damage. <br>
Mounting the LED will not work unless the acrylic laminated sealed case (standalone version) or the 60% universal case is transparent. <br>

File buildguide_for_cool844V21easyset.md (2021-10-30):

# cool844V2簡易セットビルドガイド（ver.2.1対応)

### ＜特徴＞
cool844V2（ver.2.1）はm.kiが設計した自作キーボードです。
<br>
60%自作キーボード用の汎用ケースに収納して使うことは、
これまでのcool844と同じです。<br>
cool844（ver.1.xx）と比べて、汎用ケースとの干渉を考えず、使用できます。<br>
<br>

cool844V2　別売り60%汎用ケース（木製ケースを使用）

cool844V2　ケース収納前

注意　上の完成画像で使われている透明なスイッチプレートは、
豪華セットに同封されるものです。<br>
簡易セットでは、黒色のスイッチプレートとなり、落ち着いた感じになります。<br>
<br>
# 0　参考
cool844V2は基本、cool844と同じです。組み立てに困りましたら、cool844の[ビルドガイド](https://github.com/telzo2000/cool844/blob/main/buildguideforcool844.md)を参考にしてください。<br>
必ず一読してから、組み立てを行ってください。
<br>

# 1　部品の確認
本品はスイッチプレート、PCB、
”ゲタ” 換装用アクリルプレート　１枚、
マイクロUSB端子（オス）付きケーブル、M2スペーサー３mm14本、M2ねじ８mm７本、M2ねじ４mm13本で構成されています。<br>
<br>
次のものは各自でご用意ください。<br>
ダイオード44個、スイッチソケット44個、リセットスイッチ１個、pro micro１個、スプリングピンヘッダ（マックエイトコンスルー）２個、
スタビライザー２U ３個、USBタイプC基板１個の他、<br>
お気に入りのキーキャップセットとなります。<br>
<br>

<br>

# 2　ダイオードのハンダ付け
PCB基板の下面（基板の右隅に「cool844V2」と印字されている面が上面です）に、「diode」と印字されています。印字されている面から差し込んで、上面からはんだ付けしてください。向きに注意してはんだ付けしてください。<br>


<br>

# 3　スイッチソケットのハンダ付け
PCB基板の下面に、「Socket」を印字されています。印字が見えないようにスイッチソケットを乗せて、ハンダ付けをしてください。スイッチソケットには向きがあります。向きを間違えると、キースイッチが入らなくなります。<br>
正しい向きに乗せた場合

間違った向きに乗せた場合（「Socket」の印字が見えます）
間違った向き
<br>
# 4　リセットスイッチのハンダ付け
PCB基板の下面に、「RESET」と印字されています。印字が見ねないようにリセットスイッチを乗せて、上面からハンダ付けをしてください。<br>
<br>
# ５　pro microのハンダ付け
PCB基板の下面に、スプリングピンヘッダ２個をそれぞれ、差し込んでください。<br>
スプリングヘッダには側面に、小さな穴が空いています。
穴が空いている向きを揃える必要があります。

スプリングピンヘッダにpro microを差し込んで、pro microとスプリングピンヘッダをハンダ付けをしてください。PCBとスプリングピンヘッダのハンダ付けは不要です。
pro microの向きに注意ください。<br>


<br>
# ６　ドーターボードの作成
付属のマイクロUSB端子（オス）付きケーブルを必要な長さに切ります。<br>

最初に端子側から19cmほどのところで切ります。
その後、黒い皮膜が16cmほど、その先は３cmほど残してください。<br>
４色に分かれているケーブルの皮膜を剥いて、それぞれをUSBタイプC基板の端子にハンダ付けしてください。
赤色をVBUS、白色をD-、緑色をD+、黒色をGNDにつないでください。


次に、USBタイプC基板をPCBにハンダ付けで固定します。<br>
最初にピンヘッダをUSBタイプC基板側に取り付けてください。
次の画像を参考にしてください。




次にPCB側にハンダ付けをします.<br>
PCBとUSBタイプC基板との間隔は、3.5〜4.0mmにして固定してください。
<br>

# 7　スタビライザーの装着
PCB基板の上面にスタビライザー2Uサイズを３箇所を装着してください。<br>

<br>

# 8 スイッチプレートの装着
PCBにスイッチプレートを装着します。<br>
M2ねじ8mmをスイッチプレート、M2スペーサー3mm、PCBの順でネジ締めを、７箇所行います。<br>
<br>

# 9　キースイッチの装着
それぞれのキーソケットに、キースイッチを装着します。装着の際、キースイッチの端子が曲がってしまい、きちんとささらないことがあります。もし、入力できない時は、端子の確認を最初にしてください。それでも改善しないときは、キーソケットのハンダ付けが剥がれていることがあります。<br>
<br>

# 10　60%汎用ケースへの換装
ケースはcool844と同じように、GH60系60％キーボードケースを使うことが前提になっています。
国内では遊舎工房やTalp Keyboard等で、海外ではAli Expresse等で同じようなケースを材質ごとに、見つけることができます。
cool844V2がケース全てに使えるか確認することは、個人の裁量を超えます。購入者の自己責任でお願いします。<br>
令和３年９月18日時点では、私個人で所有している５つのケースでの使用を確認しています。<br>
ただし、ケースごとに若干個体差があるようで、端子挿入口の高さや、
本体内部のねじ穴位置が少し違います。<br>
その際は、ゲタのネジでの固定位置を減らすことや、USBタイプC基板の設置する高さの修正をしてください。<br>
または、ネジ穴を拡張して対応する等、個々の対応となります。<br>
次の換装例では、ネジ穴の拡張をせず、固定するネジを減らしまして対応しましたが、使用上、問題はなかったです。
## 換装例１ 木製ケース（Talp　Keyboardで購入）　



## 換装例２　プラスチックケース（遊舎工房で購入）



## 換装例３　TOFUケース（遊舎工房で購入）




## 換装例４　MelGeek Mojo60ケース（Talp Keyboardで購入）



## 換装例4　Light Edgeケース（Talp Keyboardで購入）


## 換装方法
ゲタと名付けたアクリルプレートのねじ穴７箇所に
M2ネジ４mmでM2スペーサー3mmを固定します。<br>
場所を下の画像を参考にしてください。

この後、ゲタを汎用ケース内に置き、M2ネジ3mmで固定します。<br>
その前に、一度、cool844V2は、その上部のネジを緩めて、上下に分けてください。<br>
上部はスイッチプレート、ミドルプレート上、PCBで構成されています。上部を、先程作ったゲタに合わせてください。
この作業は、PCB下部を這っているUSBタイプC端子付きケーブルがゲタの固定を邪魔していないか確認するためのものです。
邪魔するようであれば、ケーブルの取り回しを調整してください。
また、ケーブルとスイッチソケットが重なっていると、ゲタが上手に固定できない問題があります。
ケーブルを取り回す際、勢い余って、pro microの端子に負荷をかけて、もげないよう注意してください。
<br>
ゲタの装着に問題ないことが確認できましたら、ゲタを一旦外して、汎用ケース内に戻して、ネジで固定してください。<br>

ネジの固定ができましたら、上部を汎用ケースに乗せて、上部にあるネジ７箇所で固定してください。
<br>

# 11　キーキャップの装着
お気に入りのキーキャップを装着して完成です。<br>

<br>

# 12　ファームウェア
cool844と同じものが使えます。<br>
[REMAP](https://remap-keys.app/configure)に対応しています。REMAPではcool844と表示されますが、問題ありません。<br>
[Yoichiro Tanaka@yoichiro](https://twitter.com/yoichiro)さん等が開発した[REMAP](https://remap-keys.app/)が使用できます。
<br>

**ファームウェアの書き込み**
<br>
pro microとPCをUSBケーブルで繋ぎ、google chromeで[REMAP](https://remap-keys.app/)サイトへアクセスしてください。<br>



画面中央の「KEYBOARD CATALOG」をクリックしてください。<br>
画面が変わりましたら、左上の「Keyboard Name」に「cool」と
入力して、下部の「SEARCH」をクリックしてください。
<br>
coolシリーズのキーボードが表示されます。

この中から、該当するキーボードを選び、クリックしてください。
<br>
例えば、cool844であれば、次の画面に変わります。
そこでタブの「FIRMWARE」をクリックすると、

このように、via用hexファイルが表示されます。
「FLASH」をクリックすると、

Flash Firmwareが起動して、pro microへの書き込みができます。
<br>
以上で、pro microへのファームウェアの書き込みは完了です。
<br>
<br>
**キーレイアウトの編集**
<br>
google chromeが動くパソコンとcool847をUSBケーブルでつなぎます。<br>
そのあと、[REMAP](https://remap-keys.app/configure)にアクセスして、 


画面中央の「＋KEYBOARD」をクリックしてください。<br>
<br>

キーボードとパソコンが繋がっていれば、次のような表示でます。

cool844を選び、「接続」をクリックしてください。<br>



そうすると、REMAPのサイト上で、cool844のキーレイアウトを編集することができます。

REMAPのおかげで、自作キーボードのファームウェアの書き込み、キーレイアウトの変更が大変、簡単になりました。
<br>

# 13　LEDについて
任意で、LEDを装着して光らせることができます。<br>
cool844V2は、
LEDテープ（フルカラーシリアルLEDテープ）または、SK6812MINI-Eに対応しています。<br>
ハンダ付けに自信がない人は、LEDテープをお勧めします。<br>
PCB裏面に中央部にLEDテープを装着するため、GND、VCC、LEDの端子があります。
LEDテープは、テープの端子と、その端子をつなぐように、ハンダ付けしてください。<br>
SK6812MINI-Eは、必要個数10を、中央から左右に広がる四角形の枠に納めていって、それぞれハンダ付けをしてください。<br>
SK6812MINI-Eをハンダ付けする際は、コテの温度を220℃ほどで行ってください。温度が高いと、破損する恐れがあります。<br>
LEDの装着は、60％汎用ケースが透過される透明なものでないかぎり、効果ありません。<br>

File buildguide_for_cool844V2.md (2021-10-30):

# cool844V2ビルドガイド（ver.2.0対応)


# 0　参考
cool844V2は基本、cool844と同じです。組み立てに困りましたら、cool844の[ビルドガイド](https://github.com/telzo2000/cool844/blob/main/buildguideforcool844.md)を参考にしてください。<br>
<br>

# 1　部品の確認
本品はスイッチプレート、PCB、ボトムプレート大、ボトムプレート小（２枚）の他、次のものは各自でご用意ください。<br>
ダイオード44個、スイッチソケット44個、リセットスイッチ１個、pro micro１個、スプリングピンヘッダ（マックエイトコンスルー）２個、
M2ねじ４mm３本、M2ねじ８mm11本、M2スペーサー３mm７本、M2スペーサー６mm７本、スタビライザー２U ３個、マイクロUSB端子（オス）１個、USBタイプC基板１個、ケーブル60cm程度、
お気に入りのキーキャップセットとなります。<br>
<br>
# 2　ダイオードのハンダ付け
PCB基板の下面（基板の右隅に「cool844V2」と印字されている面が上面です）に、「diode」と印字されています。印字されている面から差し込んで、上面からはんだ付けしてください。向きに注意してはんだ付けしてください。<br>


<br>

# 3　スイッチソケットのハンダ付け
PCB基板の下面に、「Socket」を印字されています。印字が見えないようにスイッチソケットを乗せて、ハンダ付けをしてください。スイッチソケットには向きがあります。向きを間違えると、キースイッチが入らなくなります。<br>
正しい向きに乗せた場合

間違った向きに乗せた場合（「Socket」の印字が見えます）
間違った向き
<br>
# 4　リセットスイッチのハンダ付け
PCB基板の下面に、「RESET」と印字されています。印字が見ねないようにリセットスイッチを乗せて、上面からハンダ付けをしてください。<br>
<br>
# ５　pro microのハンダ付け
PCB基板の下面に、スプリングピンヘッダ２個をそれぞれ、差し込んでください。<br>
スプリングピンヘッダにpro microを差し込んで、pro microとスプリングピンヘッダをハンダ付けをしてください。PCBとスプリングピンヘッダのハンダ付けは不要です。<br>
<br>
# ６　ドーターボードの作成
[これ](https://github.com/telzo2000/Hello_keyboard/blob/main/dbforcool844/buildlog.md)を参考にしてください。<br>
作成したドーターボードは、USB-C端子側をPCBに触れるように置いて、ハンダ付けで固定します。<br>

マイクロUSB端子は、pro microの端子に装着してください。<br>
マイクロUSB端子（オス）付きケーブルが同封されている場合、赤色をVBUS、白色をD-、緑色をD+、黒色をGNDにつないでください。<br>
USBタイプC基板には、GND端子が２箇所ありますが、どちらでも構いません。また、ケーブルの長さは調節して使用してください。<br>
（追記）<br>
オプション部品（ゲタ及びボトムプレート改良版）を使用される場合、ドーターボードの取り付ける向きは、USBタイプCが下に来る向きでハンダ付けをしてください。<br>
その際、PCBとドーターボードの基板との間隔３〜４mmとしてください。
この間隔については、汎用ケースに装着した際、汎用ケースのUCB端子の挿入口に過不足なく、合致するかに関係します。
装着する予定の汎用ケースを持っている場合は、仮合わせをしてからハンダ付けをすることをお勧めします。<br>
個人の感想ですが、TOFUケースですと、４mmは確実に必要です。<br>
プラスチックケースですと、３mmぐらいです。<br>
木製ケースですと、その間で3.5mmぐらいです。<br>
ドーターボードのUSBタイプCを下向きに固定した場合、従来のボトムプレートでは干渉して装着できません。<br>
ゲタと一緒に同封されるボトムプレート改良版をしようすれば、スタンドアローンとしてcool844V2が使用できます。<br>
<br>
# 7　スタビライザーの装着
PCB基板の上面にスタビライザー2Uサイズを３箇所を装着してください。<br>

<br>

# 8 スイッチプレートの装着
PCBにスイッチプレートを装着します。<br>
M2ねじ8mmをスイッチプレート、M2スペーサー3mm、PCB、M2スペーサー6mmの順でネジ締めを、７箇所行います。<br>
<br>
# 9　キースイッチの装着
それぞれのキーソケットに、キースイッチを装着します。装着の際、キースイッチの端子が曲がってしまい、きちんとささらないことがあります。もし、入力できない時は、端子の確認を最初にしてください。それでも改善しないときは、キーソケットのハンダ付けが剥がれていることがあります。<br>
<br>
# 10　ボトムプレートの装着
ボトムプレート大を乗せて、手前側３箇所のネジ穴には、M2ねじ４mmでねじ締めします。次に、ボトムプレート小２枚を重ねて、ボトムプレート奥側に置きます。奥側４箇所のねじ穴には、M2ねじ8mmでねじ締めをします。<br>
この後、任意でゴム足をボト、ボトムプレートの四隅に装着すると、滑りにくくなります。<br>
<br>
# 11　キーキャップの装着
お気に入りのキーキャップを装着して完成です。<br>

<br>
# 12　ファームウェア
このキーボードはQMKというキーボード用のソフトウェアで動作するようにプログラミングしています。<br>
[Yoichiro Tanaka@yoichiro](https://twitter.com/yoichiro)さん等が開発した[REMAP](https://remap-keys.app/)が使用できます。
<br>

**ファームウェアの書き込み**
<br>
pro microとPCをUSBケーブルで繋ぎ、google chromeで[REMAP](https://remap-keys.app/)サイトへアクセスしてください。<br>



画面中央の「KEYBOARD CATALOG」をクリックしてください。<br>
画面が変わりましたら、左上の「Keyboard Name」に「cool」と
入力して、下部の「SEARCH」をクリックしてください。
<br>
coolシリーズのキーボードが表示されます。

この中から、該当するキーボードを選び、クリックしてください。
<br>
例えば、cool844であれば、次の画面に変わります。
そこでタブの「FIRMWARE」をクリックすると、

このように、via用hexファイルが表示されます。
「FLASH」をクリックすると、

Flash Firmwareが起動して、pro microへの書き込みができます。
<br>
以上で、pro microへのファームウェアの書き込みは完了です。
<br>
<br>
**キーレイアウトの編集**
<br>
google chromeが動くパソコンとcool847をUSBケーブルでつなぎます。<br>
そのあと、[REMAP](https://remap-keys.app/configure)にアクセスして、 


画面中央の「＋KEYBOARD」をクリックしてください。<br>
<br>

キーボードとパソコンが繋がっていれば、次のような表示でます。

cool844を選び、「接続」をクリックしてください。<br>



そうすると、REMAPのサイト上で、cool844のキーレイアウトを編集することができます。

REMAPのおかげで、自作キーボードのファームウェアの書き込み、キーレイアウトの変更が大変、簡単になりました。
<br>
<br>
